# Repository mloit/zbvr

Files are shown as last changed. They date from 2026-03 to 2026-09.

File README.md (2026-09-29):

# Vintage AM Radio Inspired Offline MP3 Player PCB

***Complete PCB design files and documentation coming soon!***

## Announcements 

- ***NEW:*** [26.0.2 firmware](https://github.com/mloit/zbvr-firmware) (Latest release available on the [Releases page](https://github.com/mloit/zbvr-firmware/releases/latest))

- ***New:*** [Big Speaker Option](./docs/Big%20Speaker%20Assembly%20Guide.md)

- ***New*** BOM's for PCB upgrade and battery module (see below)

- ***Coming Soon:*** Battery module PCB and assembly guides

---

Want to support my efforts? Feel free to [Buy me a Coffee][support]
---

## Docs
- [PCB Assembly Guide](./docs/PCB%20Assembly%20Guide.md)

- [Wiring Harness Assembly Guide](./docs/Wiring%20Harness%20Assembly%20Guide.md)

## Errata
A number of boards have been exhibiting a problem when turning on the radio via the potentiometer, the connection to Thonny (or other serial terminal) is lost. This appears to be due to a dip in voltage as a result of the inrush current to charg up the amplifier circuit. To address this I recommend soldering a 100uF electrolytic (Digikey: 1189-2195-ND, or similar) between the 5V and Gnd pins of the GPIO connector (J10) located between the RP-Zero and the DFPlayer

---
## The PCB
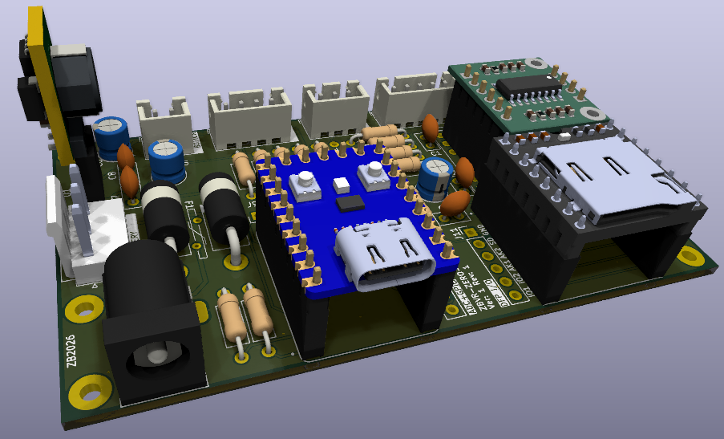
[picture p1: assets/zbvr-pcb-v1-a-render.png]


### Schematic 
(Click Image for PDF)
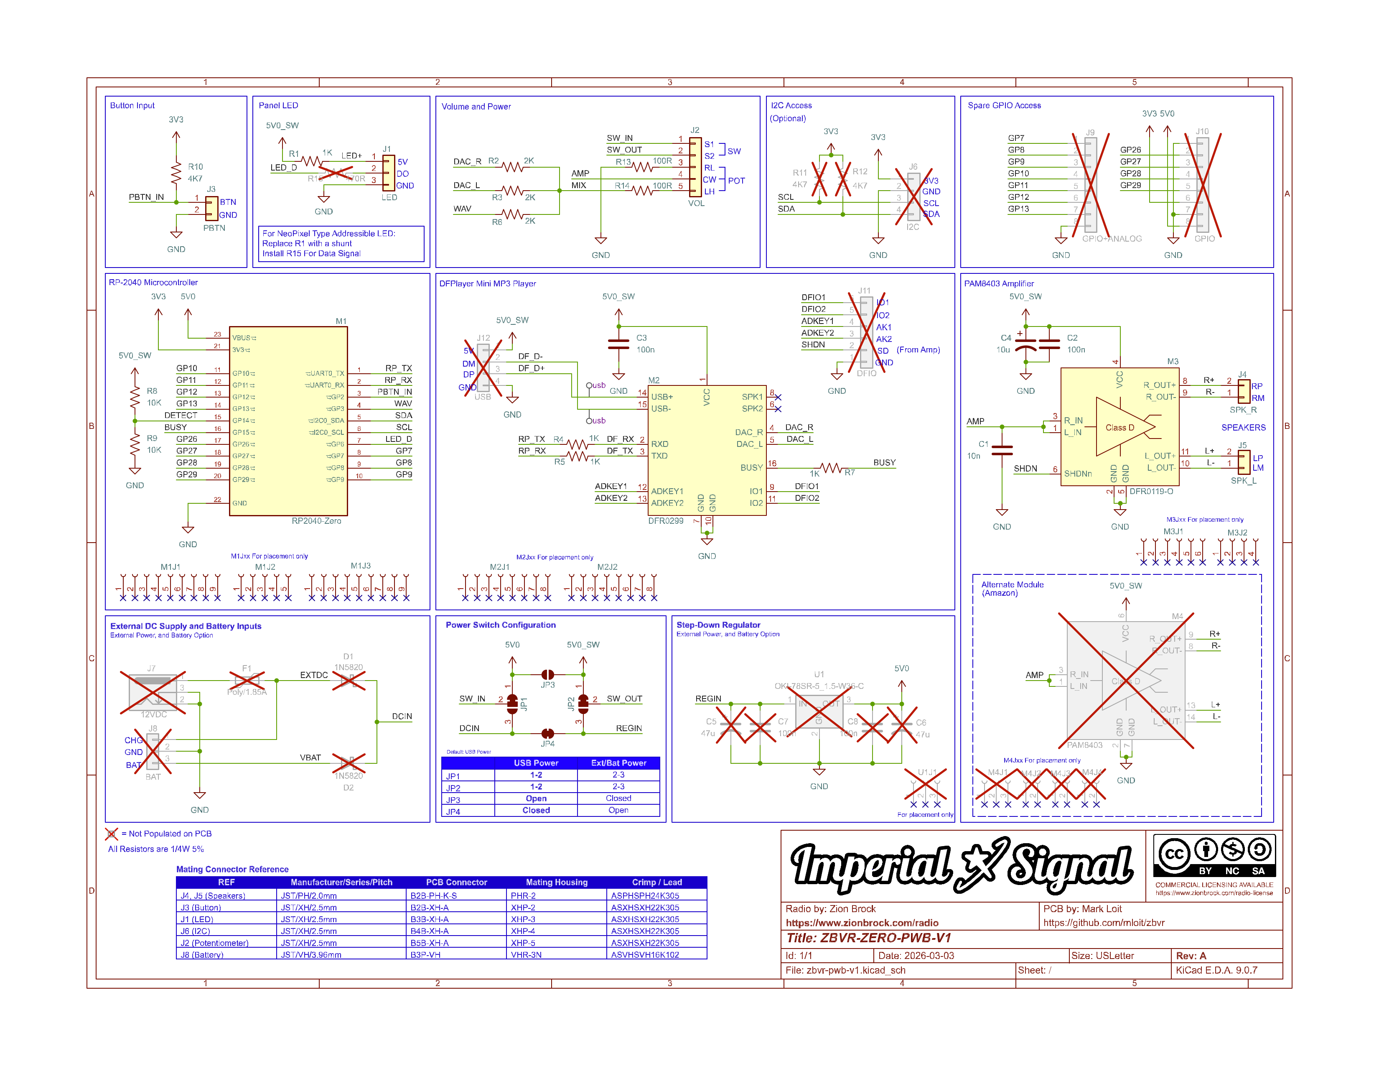
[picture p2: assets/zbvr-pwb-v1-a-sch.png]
[](./assets/zbvr-pwb-v1-a-sch.pdf)

### Top/Component Side of PCB:
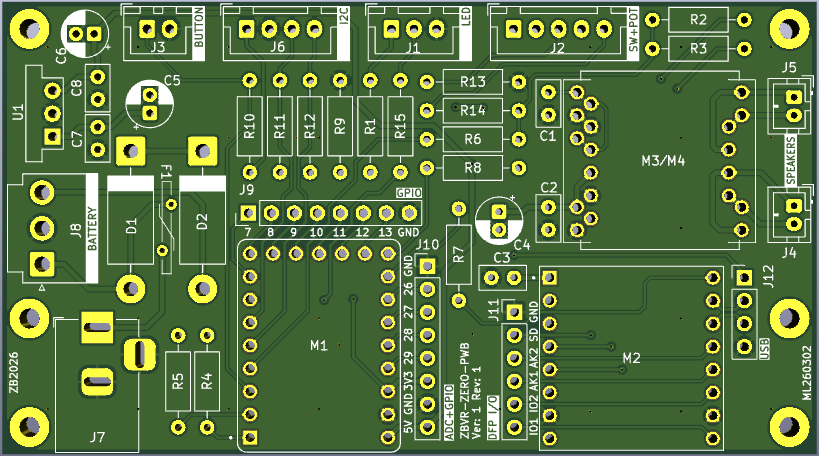
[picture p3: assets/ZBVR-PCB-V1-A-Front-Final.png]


### Bottom/Solder Side of PCB:
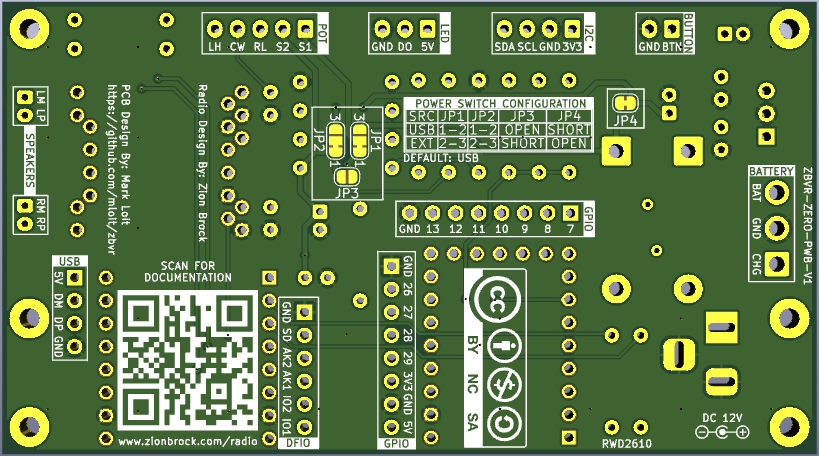
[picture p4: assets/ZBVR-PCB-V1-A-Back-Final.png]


---

## Building your own

The first step to building your own will be to get your hands on a bare PCB. PCB's can currently be ordered from our [Community project at PCBWay][pcbway]. This is currently the preferred route as we do earn a small commission on every board ordered from there to help support the project (anything earned on the PCB's is shared between Zion and myself). Also please note that if you plan to resell the PCB's we ask that you fill out a [license application][zion-lic] on Zion's project site.

For the components you can use this [list at DigiKey][dk-pcb] as a starting point. The list includes everything except the speakers, RP2040-Zero, and push-button, for the basic configuration of the PCB. Details on a more complete configuration for external power and a battery will be provided in the near future.

In terms of the 3D printed parts, for the PCB version you want to print the "Shell Normal - with button" version of the shell, from the "Shells" 3MF profile. From the "Mounts" 3MF profile you want to print the "Circuit Board Mount (PCB Version)" plate. (Optionally, if building for the "Big Speaker Option", you would print that mount instead)  All other radio parts (except for the back plate, see next section) are common, and the same for any version of the device. You may optionally print the "Soldering Aids" 3MF for some jigs and tools to make assembling the PCB a bit easier.

#### Radio Back Plate

Depending on which verion of the PCB you are plannning to build/use the back plate changes. The "Standard" version is powered by USB, while the "Full" version used with the battery option requires an external DC power supply. (The full version can be used without the battery, but still requires the external DC supply) The Full version is not compatable with being powered over USB, as such 2 versions of the back plate have been designed. One with the USB opening for the "Standard" buikd, and one with a hole for the external DC suppply for the "Full" version. Please be sure to print the correct version of the back plate for the version of the PCB you are going to assemble. 

- Standard PCB Build: "Back Plate for PCB Version"
- Full PCB Build: "Back Plate for PCB Battery Version"

#### Battery & Big Speaker Options

Note that the "Big Speaker Option" profile I have here currently does not have mounts for the battery module. I will be updating this soon to add the mounting points. If building now, I recommend using Hook and Loop (Velcro) adhesive fastener strips to attach he battery module to the back of the speaker shell. All versions of the PCB here support the big speaker, so no changes are required on the PCB itself.

Note the BOM's for the battery do NOT include teh external DC supplpy, as it will depend on your region. The requrements are 10W or more power, 9-12V. 5.5mm barrel with 2.1mm pin, centre positive.

- Example for North America: [GlobTek WR9HD1333CCP-F(R6B)][dk-psu-us] (Digikey)

### Before you purchase components
The board is designed to support either the amplifier module from DigiKey, or the amplifier module originally demonstrated by Zion in his video, from Amazon. If you have already purchased components from Amazon, you can omit getting them from the list provided above. Note that if you are going with the Amazon Amplifier this affcts a few lines in the list. With the exception of the items mentioned earlier, this list here effectively replaces teh BOM currently on Zion's site.

#### If you have already purchased, or plan to use the amplifier module from Amazon

**Remove** the following 3 line items:
1. Line 2: DFR0119-O (PAM8403 Eval board) Digikey P/N: 1738-1041-ND
2. Line 26: PPTC041LFBN-RC (1x4 pos female header 2.54mm) Digikey P/N: S7002-ND
3. Line 27: PPTC061LFBN-RC (1x6 pos female header 2.54mm) Digikey P/N: S7004-ND

**Add** the following 2 items:
1. PPTC021LFBN-RC (1x2 pos female header 2.54mm) DigiKey P/N: S7000-ND - Quantity 3 per board
2. PPTC031LFBN-RC (1x3 pos female header 2.54mm) DigiKey P/N: S7001-ND - Quantity 1 per board

#### Notes on the BoM (Bill of Materials)

There are several bills of materials for the PCB, depending on which version you want to build, or are upgrading from one to the other. They all use the same base Radio PCB but are populated differently.

##### Standard Build (USB Powered)

If building the standard version fo the PCB, as featuerd in Zion's original videos about the PCB, you want to use this BOM. (Note that this version does not include support for the battery option)

- [Standard PCB Components][dk-pcb] (DigiKey)
- [Standard PCB Components Alternate][dk-pcb-alt] (DigiKey) -- for when you are using the amplifier from Amazon
- [Amplifier Module][amp] (Amazon) -- Optional/Alternate
- [RP2040-Zero][rp] (Amazon)

##### Full Build (External Powered or Battery Powered)

If you want your radio to be powered by an external DC supply, or be powered by the battery module use this BOM if building a new board. If upgrading an existing board, use the upgrade BOM below. Note that if planning to use the battery module, you need to also get the items in the "Battery Only" BOM below. Note while I have not amde an alternalte BOM for this version, you can make teh same changes as noted above if using the amplifier from Amazon.

- [Full PCB Components][dk-pcb-full] (DigiKey)
- [Amplifier Module][amp] (Amazon) -- Optional/Alternate
- [RP2040-Zero][rp] (Amazon)

**Note:** the BOM does NOT include teh external DC supplpy, as it will depend on your region. The requrements are 10W or more power, 9-12V. 5.5mm barrel with 2.1mm pin, centre positive.

- Example for North America: [GlobTek WR9HD1333CCP-F(R6B)][dk-psu-us] (Digikey)

##### Standard to Full Upgrade (with Battery)

This BOM contains only the components required to upgrade your PCB from the standard configuration to the full configuration, as well as the components for the battery module. Note if building more than one battery board, I recommend not purchasing the "PC4" battery holder on the Digikey BOM and instead ordering them on Amazon.

- [PCB Upgrade and Battery Parts][dk-pcb-upg] (DigiKey)
- [PC4 Battery holder][pc4] (Amazon)
- [Battery Charger Module][chg] (Amazon)
- [Battery Protection Module][prot] (Amazon)

**Note:** the BOM does NOT include teh external DC supplpy, as it will depend on your region. The requrements are 10W or more power, 9-12V. 5.5mm barrel with 2.1mm pin, centre positive.

- Example for North America: [GlobTek WR9HD1333CCP-F(R6B)][dk-psu-us] (Digikey)

##### Battery Only

This BOM contains just the DigiKey parts requred for the Battery Module and teh wiring to connect it to the main board. If upgrading follow the Upgrade BOM above instead. If building for the battery from the start, use the "Full Build" Bom above, and add the items in this BOM to your order as well. Note if building more than one battery board, I recommend not purchasing the "PC4" battery holder on the Digikey BOM and instead ordering them on Amazon.

- [Battery Module Parts][dk-bat] (DigiKey)
- [PC4 Battery holder][pc4] (Amazon)
- [Battery Charger Module][chg] (Amazon)
- [Battery Protection Module][prot] (Amazon)

---

## Project Links:

- [Full Project Homepage][zion-web]
- [PCB page on Zion's website][zion-build]
- [Project Discord][discord]
- [3D Print Files][zion-mw] (MakerWorld)
- [PCB Boards][pcbway] (PCBWay)
- [Standard PCB Components][dk-pcb] (DigiKey)
- [Standard PCB Components Alternate][dk-pcb-alt] (DigiKey) -- for when you are using the amplifier from Amazon
- [Full PCB Components][dk-pcb-full] (DigiKey)
- [PCB Upgrade Components][dk-pcb-upg] (DigiKey)
- [Battery Module Components][dk-bat] (DigiKey)
- [Zion Brock's YouTube][zion-yt]

---

Want to support my efforts? Feel free to [Buy me a Coffee][support]

[](./LICENSE.txt)

[cc-by-nc-sa]: ./assets/by-nc-sa.png "CC-BY-NC-SA"
[sch]: ./assets/zbvr-pwb-v1-a-sch.png "ZBVR-PWB-V1-A Schematic"
[pcb]: ./assets/zbvr-pcb-v1-a-render.png "Rendering of fully populated ZBVR-PCB-V1-A"
[front]: ./assets/ZBVR-PCB-V1-A-Front-Final.png "Top/Component Side of PCB"
[back]: ./assets/ZBVR-PCB-V1-A-Back-Final.png "Bottom/Solder Side of PCB"
[pcbway]: https://www.pcbway.com/project/shareproject/Simple_lo_fi_offline_MP3_player_for_the_Zion_Brock_vintage_radio_official_PCB_5a9d43d7.html
[dk-pcb]: https://www.digikey.com/en/mylists/list/7UZQIHX73I
[zion-web]: https://www.zionbrock.com/radio
[zion-mw]: https://makerworld.com/en/models/2163838-my-vintage-radio-offline-am-style-music-player
[zion-yt]: https://www.youtube.com/@zionbrock/videos
[discord]: https://discord.gg/p7cJ7csKEd
[zion-lic]: https://www.zionbrock.com/radio-license
[zion-build]: https://www.zionbrock.com/vintage-radio-circuit-board-pcb
[dk-pcb-alt]: https://www.digikey.com/en/mylists/list/B0VSUA3P00
[dk-pcb-full]: https://www.digikey.com/en/mylists/list/RAMKQWNZRU
[dk-pcb-upg]: https://www.digikey.com/en/mylists/list/QIRFQ48IGT
[dk-bat]: https://www.digikey.com/en/mylists/list/4W6Q9O6ATI
[dk-psu-us]: https://www.digikey.ca/en/products/detail/globtek-inc/WR9HD1333CCP-F-R6B/13245472
[rp]: https://www.amazon.com/dp/B0C5Q2V49P?ref=ppx_yo2ov_dt_b_fed_asin_title&th=1
[amp]: https://www.amazon.com/HiLetgo%C2%AE-PAM8403-Digital-Amplifier-2-5-5V/dp/B00LODGV64/ref=sr_1_1_sspa?th=1
[pc4]: https://www.amazon.com/dp/B0B1JJZ363?ref=ppx_yo2ov_dt_b_fed_asin_title&th=1
[chg]: https://www.amazon.com/Bloepum-Charging-Management-Lithium-Battery/dp/B0FB8K6PVR
[prot]: https://www.amazon.com/dp/B0DDY32WF4?ref=ppx_yo2ov_dt_b_fed_asin_title
[support]: https://buymeacoffee.com/canadianavenger

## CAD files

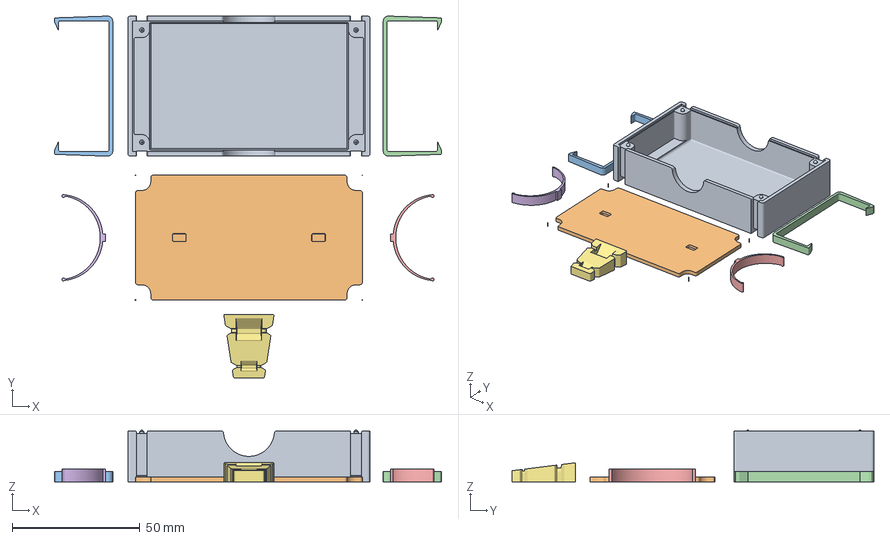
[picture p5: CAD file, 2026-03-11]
assets/assembly-jigs.3mf
151.9 x 142.0 x 20.3 mm
soldering aid.stl
soldering-aid-plate.stl
soldering-aid-clip.stl x 2
soldering-aid-spring.stl x 2
bend-aid-new.stl

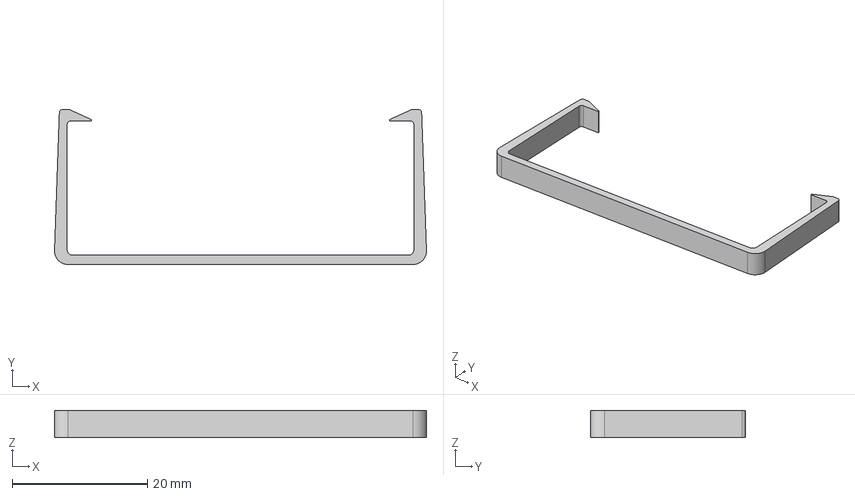
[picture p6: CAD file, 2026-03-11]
3D CAD Models/soldering aids/soldering-aid-clip.step
55.0 x 22.9 x 4.00 mm

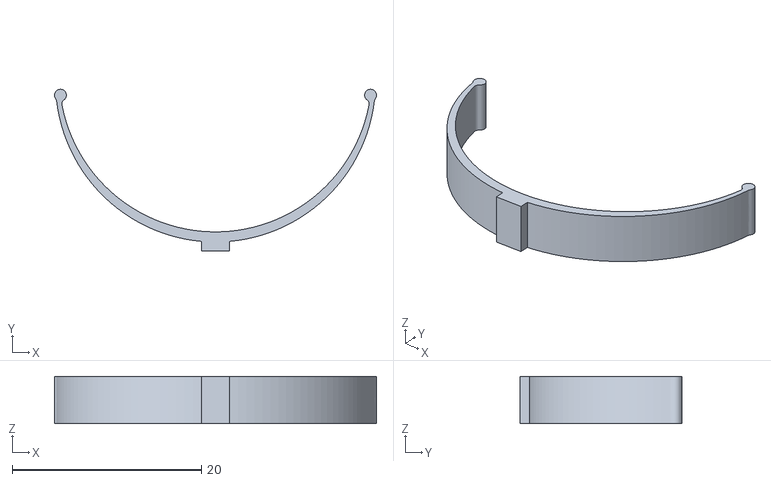
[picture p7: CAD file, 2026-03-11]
assets/soldering-aids/soldering-aid-spring.stl
34.0 x 17.1 x 5.00

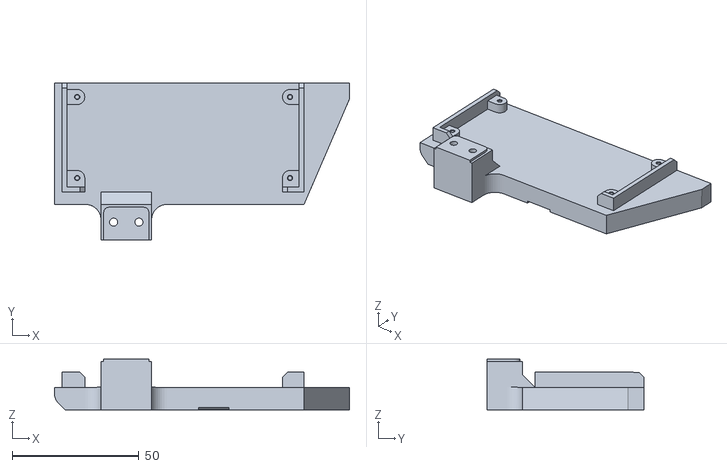
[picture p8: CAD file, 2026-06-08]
assets/speaker/mount-big-spkr.stl
116.4 x 61.9 x 20.0

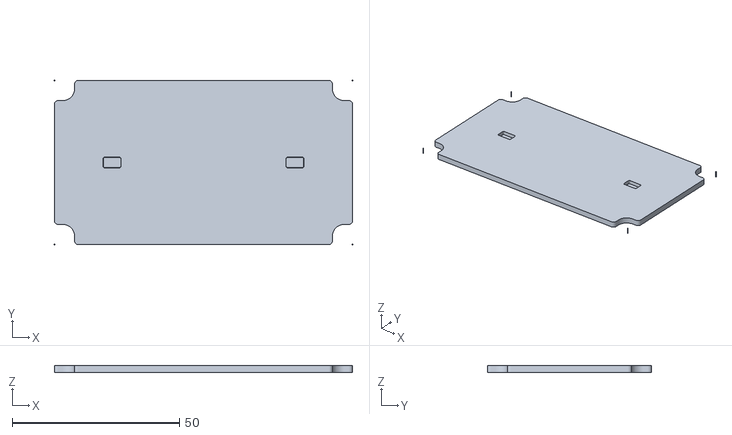
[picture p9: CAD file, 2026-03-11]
assets/soldering-aids/soldering-aid-plate.stl
89.0 x 49.0 x 2.00

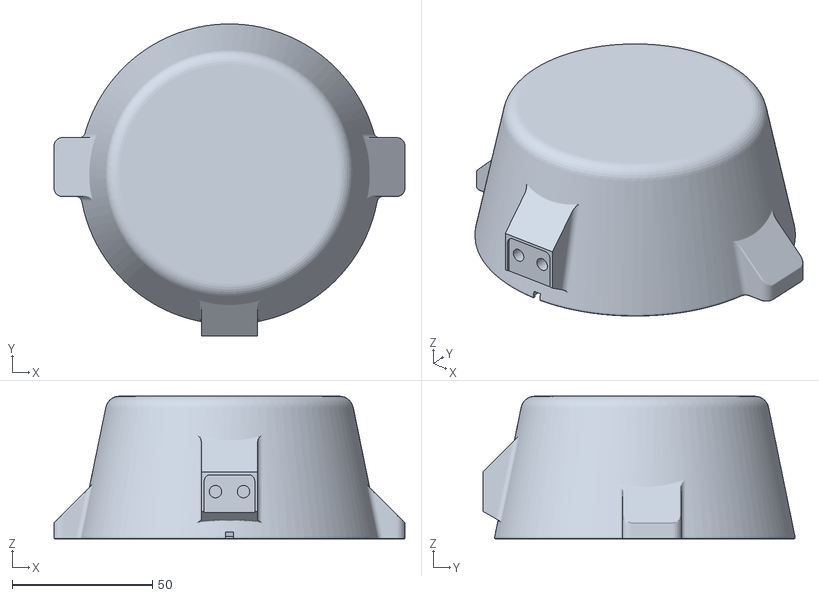
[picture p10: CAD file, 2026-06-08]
assets/speaker/GRS-3AS-4-cup.stl
125.0 x 111.1 x 50.8

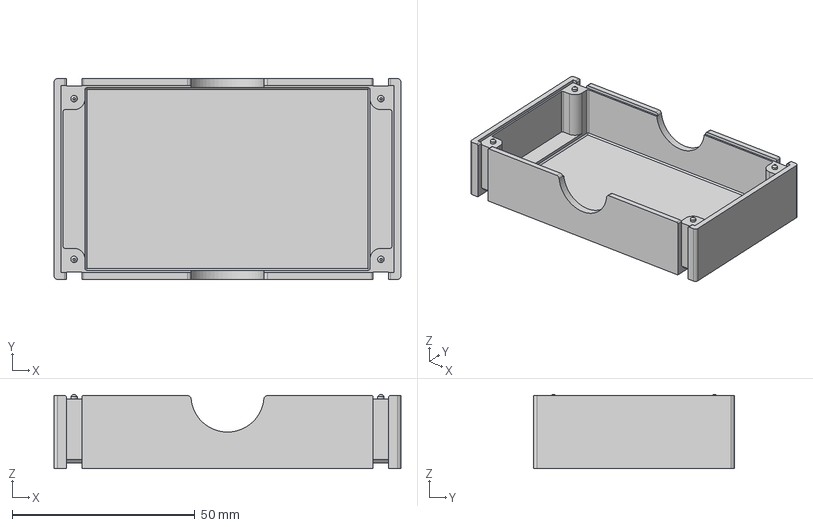
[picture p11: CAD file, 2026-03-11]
3D CAD Models/soldering aids/soldering aid.step
95.0 x 55.0 x 20.3 mm

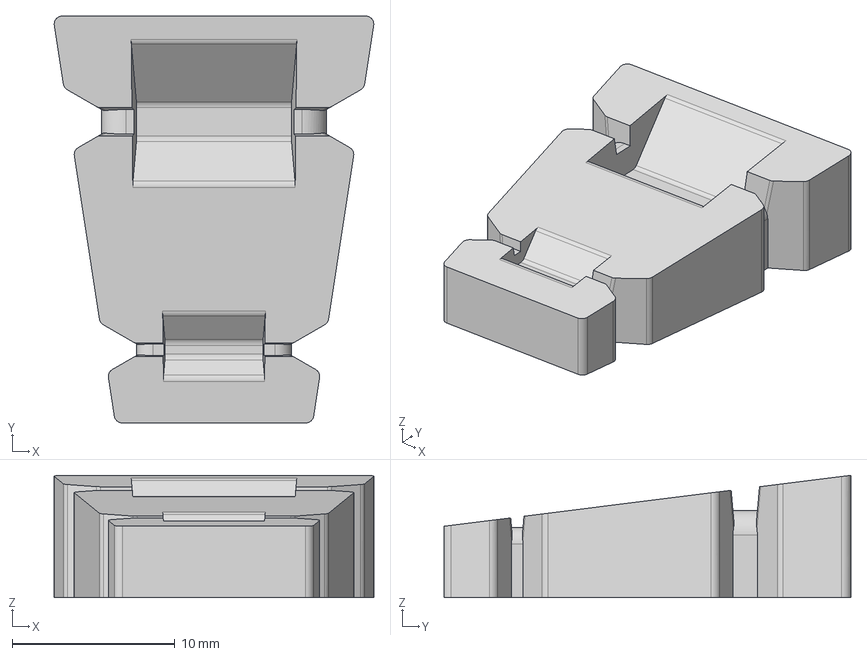
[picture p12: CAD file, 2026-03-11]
3D CAD Models/soldering aids/bend-aid-new.step
19.6 x 25.0 x 7.52 mm

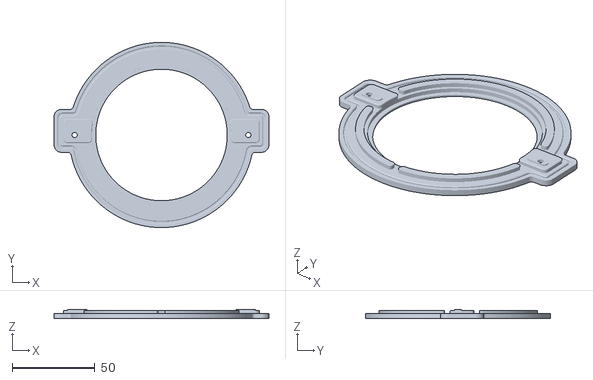
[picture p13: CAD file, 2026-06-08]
assets/speaker/GRS-3AS-4-ring.stl
130.0 x 112.0 x 5.60

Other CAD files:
3D CAD Models/soldering aids/soldering-aid-spring.step
assets/soldering-aids/soldering-aid-clip.stl
assets/soldering-aids/soldering-aid.stl
3D CAD Models/soldering aids/soldering-aid-plate.step
assets/soldering-aids/bend-aid-new.stl

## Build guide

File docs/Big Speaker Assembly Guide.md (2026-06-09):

# Big Speaker Assembly Guide

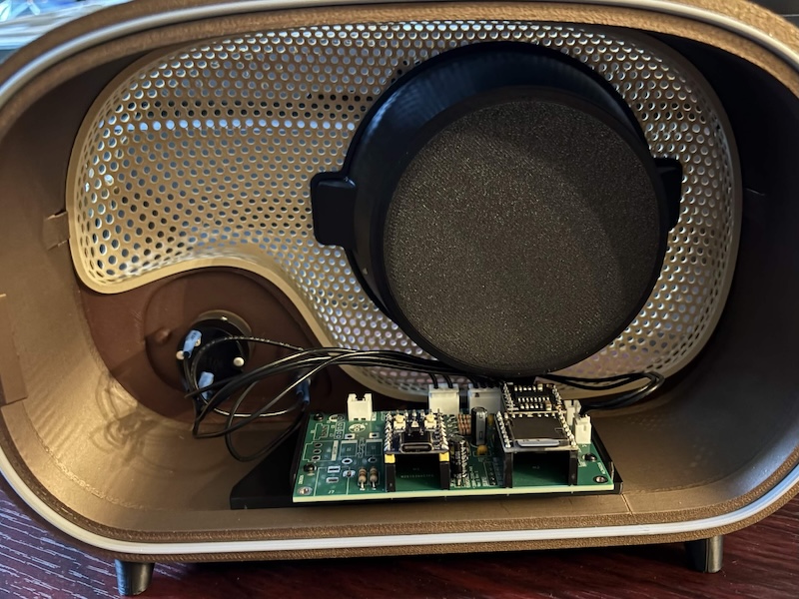
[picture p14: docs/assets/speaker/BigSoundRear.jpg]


So you build the [radio with the PCB][1], but wanted bigger sound from it. This guide is here to help with that. I've designed a new mount and enclosure for a 3.5in car speaker that is fairly inexpensive, and fairly easy to obtain. The solution here isn't perfect, but sounds quite good. The only real downside is that the PCB needs to be mounted on the mount and the potentiometer plugged in before the speaker can be mounted. (you may want to have the LED connected as well beforehand) 

[1]: https://www.zionbrock.com/radio
[begin]: ./assets/speaker/BigSoundRear.jpg "Assembled Speaker and Mount"

---

## Materials

- 1x 3D Printed speaker mount and enclosure
	- [All Parts 3MF](/assets/speaker/big-speaker.3mf) 
	- [All Parts STL/ZIP](/assets/speaker/big-speaker.zip)
	- Individual STL files
		- 1x [Mount](/assets/speaker/mount-big-spkr.stl)
		- 1x [Speaker Cup](/assets/speaker/GRS-3AS-4-cup.stl)
		- 1x [Face Ring](/assets/speaker/GRS-3AS-4-ring.stl)
- 6x M3 Threaded heat-set insert nuts
	- [Maker World M3x5x4](https://ca.store.bambulab.com/products/round-threaded-brass-heat-insert-nut) AB012
	- [CNC Kitchen M3x5x4](https://cnckitchen.store/products/made-for-voron-gewindeeinsatz-threaded-insert-m3x5x4-100-stk-pcs)
- 2x M3x6 SHCS (Socket Head Cap Screws) - for mounting assembly in radio
	- [Maker World M3x6 SHCS](https://ca.store.bambulab.com/products/m3-socket-head-cap-machine-screws-shcs-1) AA036
- 2x M3x10 SHCS (Socket Head Cap Screws) - attaching speaker to mount
	- [Maker World M3x10 SHCS](https://ca.store.bambulab.com/products/m3-socket-head-cap-machine-screws-shcs-1) AA159
- 2x M3x8 BHCS (Button Head Cap Screws) - attaching ring to cup
	- [Maker World M3x8 BHCS](https://ca.store.bambulab.com/products/m3-button-head-cap-machine-screws-bhcs) AA058
- 4x BT2x6 SHCSST (Socket Head Cap Screw Self Tapping) - Attaching PCB to mount
	- [Maker World BT2x6 SHCS](https://ca.store.bambulab.com/products/bt2-socket-head-cap-self-tapping-screws-shcs-new) AA093
	- [Maker World BT2x6 BHCS](https://ca.store.bambulab.com/products/bt2-button-head-cap-self-tapping-screw-bhcs) AA128 (Old Button Head Version) 
- 1x GRS 3AS-4 3.5in automotive replacement speaker 4 ohm 15 Watts
	- [Parts Express](https://www.parts-express.com/GRS-3AS-4-3-1-2-Car-Replacement-Speaker-4-Ohm-292-452?quantity=1) (USA)
	- [Solen Online](https://www.solen.ca/en/products/GRS-3AS-4-87mm-Car-Replacement-Speaker-4-Ohm) (Canada)
	- [Sound Imports](https://www.soundimports.eu/en/grs-3as-4.html) (Europe)
- 1x JST PHR-2 - PH Series 2mm pitch 2 pin housing
	- Not needed if salvaging from old speaker
	- [Digikey 455-1165-ND](https://www.digikey.com/short/q53mh2v7)
	- [Mouser 306-PHR-2PP](https://mou.sr/4vBqxXr)
- 1x JST ASPHSPH24K305 - PH Series crimped 12in 24AWG lead
	- Not needed if salvaging from old speaker
	- [Digikey 455-3083-ND](https://www.digikey.com/short/qd985ztp)
	- [Mouser 306-ASPHSPH24K305](https://mou.sr/48MVWfJ)

***Note:*** *If salvaging the wire and connector from an old speaker, be sure to cut as close to the speaker as possible, you want to end up with at least 6in of wire from the cut end to the connector.*

### Additional Required Materials

- Solder

### Optional Materials

- Sealant or Glue
	- Hot Glue
	- Silicone
	- Epoxy 

## Tools
### Required Tools

- Soldering Iron
- Wire Cutters
- Wire Strippers

### Optional Tools

- Hot Glue Gun

---

## Assembly

### Mount Preparation

We'll start by installing the heat-set insert nuts

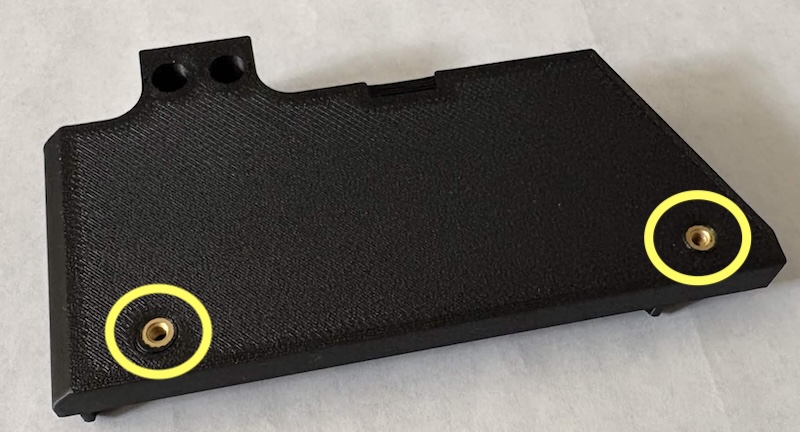
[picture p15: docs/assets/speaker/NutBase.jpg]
1. Install the heat-set nuts into the bottom of the mount as shown.<br>
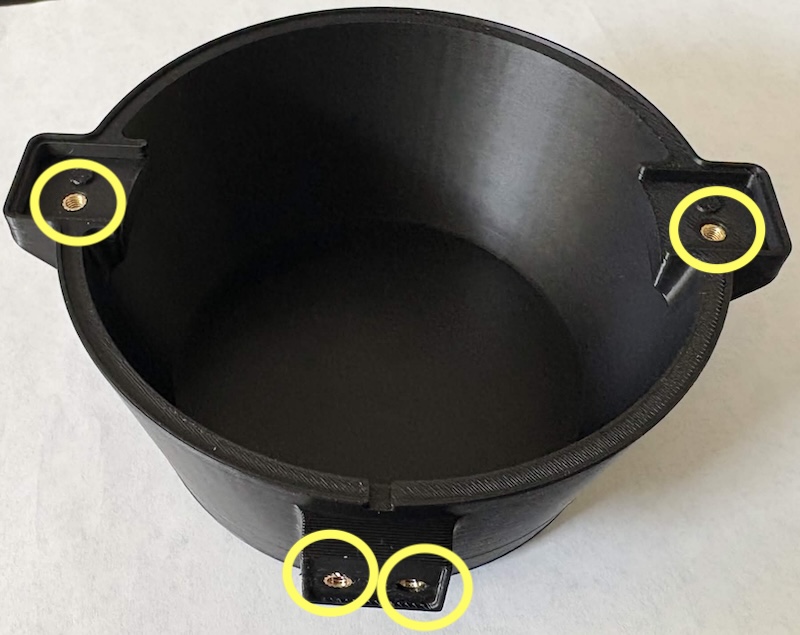
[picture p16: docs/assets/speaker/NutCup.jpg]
2. Install the heat-set nuts into the speaker cup as shown.<br>

[nut1]: ./assets/speaker/NutBase.jpg "Locations for heat inserts in mount base"
[nut2]: ./assets/speaker/NutCup.jpg "Locations for heat inserts in speaker cup"

### Speaker Preparation

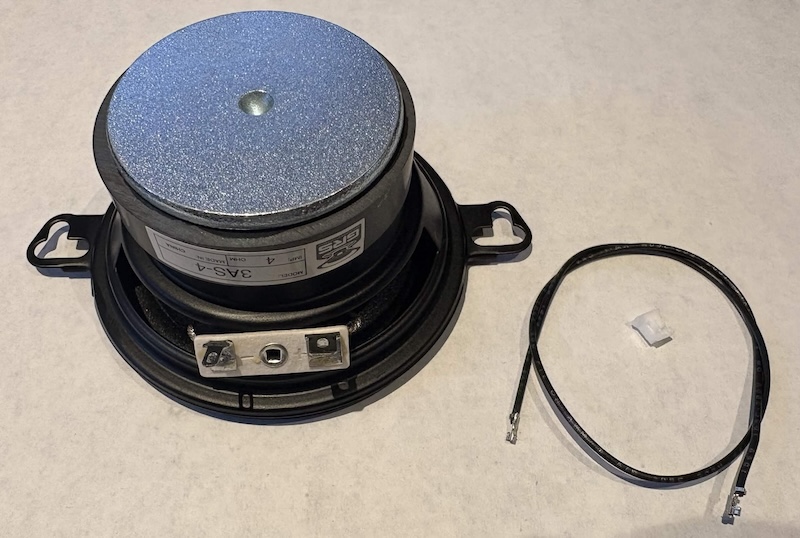
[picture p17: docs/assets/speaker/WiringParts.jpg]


Next we need to add wire leads to the speaker

1. Fold and cut the 12in wire lead in half to produce two 6in wire leads, each with a crimp on one end.
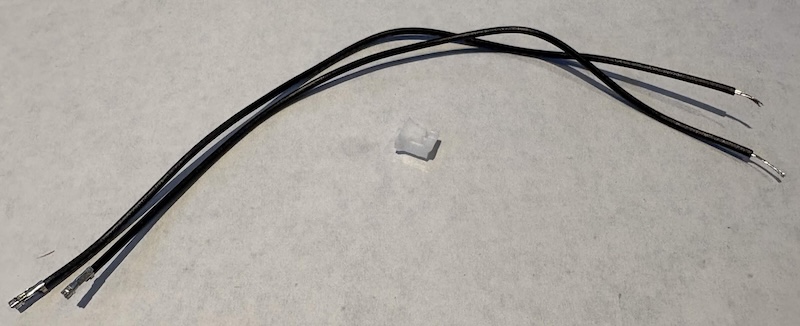
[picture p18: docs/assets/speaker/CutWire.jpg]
2. Strip the bare end of the wire exposing 3-5mm of the bare wire.<br>
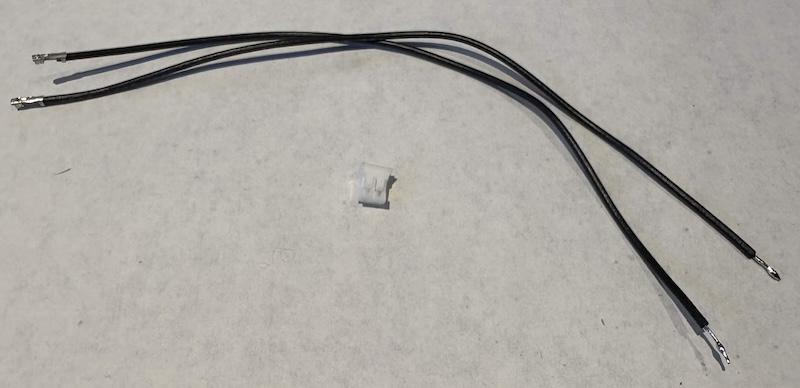
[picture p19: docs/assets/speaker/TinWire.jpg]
3. Tin the stripped wire ends with some solder.<br>
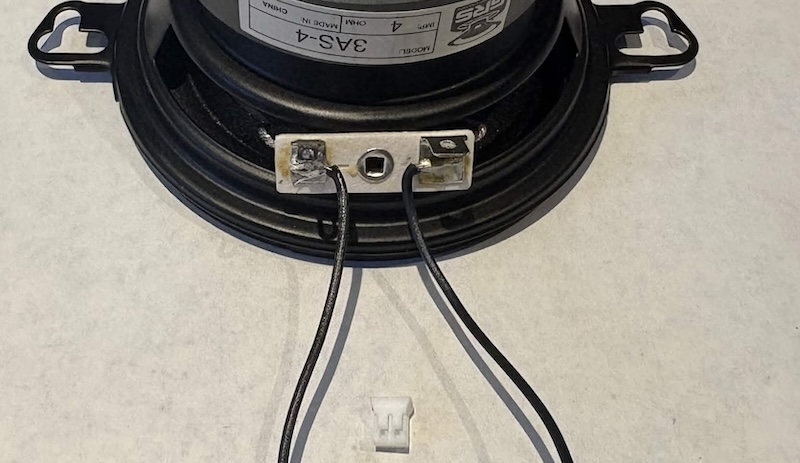
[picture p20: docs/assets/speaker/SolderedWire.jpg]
4. Solder the leads to the speaker.I find it easiest to solder to the base of the terminals where there is solder already.<br>
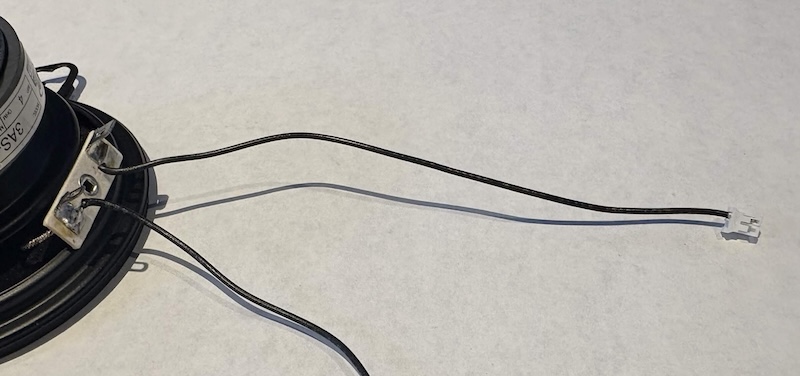
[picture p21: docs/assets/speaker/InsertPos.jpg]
5. Insert the positive lead into pin 2 of the connector housing. *(Note: polarity is not strictly important here as we only have one speaker)*<br>
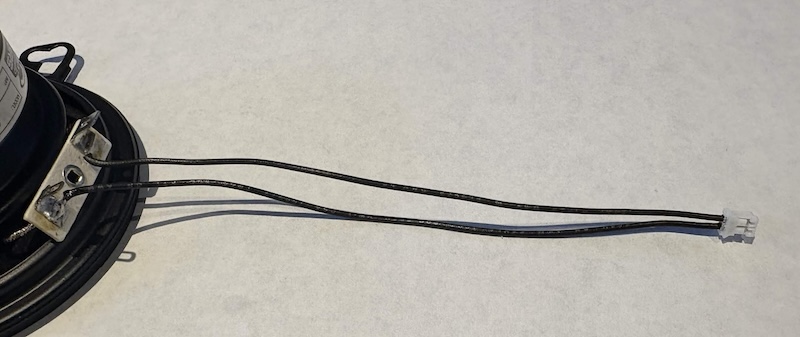
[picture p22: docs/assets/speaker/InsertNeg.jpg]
6. Insert the negative lead into pin 1 of the connector housing.<br>

[wir1]: ./assets/speaker/WiringParts.jpg "Speaker wiring parts"
[wir2]: ./assets/speaker/CutWire.jpg "Cut and stripped wire leads"
[wir3]: ./assets/speaker/TinWire.jpg "Tinned leads"
[wir4]: ./assets/speaker/SolderedWire.jpg "Wires soldered to speaker"
[wir5]: ./assets/speaker/InsertPos.jpg "Positive lead installed in connector"
[wir6]: ./assets/speaker/InsertNeg.jpg "Both leads installed in connector"

### Speaker Enclosure

Next we will assemble the speaker enclosure. The optional step of sealing around the edge is to secure the top ring better, and will prevent any rattle, as well as it should increase the performance of the enclosure slightly.

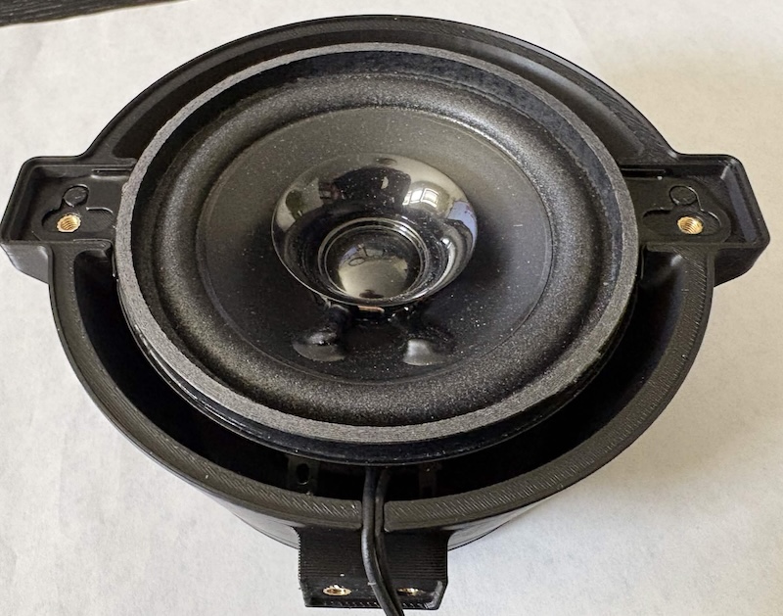
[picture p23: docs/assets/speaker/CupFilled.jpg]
1. First place the speaker  into the cup, using the bumps and slots for alignment. The wires on the speaker should be facing the small slot at the bottom, and pressed down into the slot.<br>
2. Place the Face Ring over the speaker. ***Note:*** *The tabs on the speaker are slightly off-centre so it will only fit one way.*
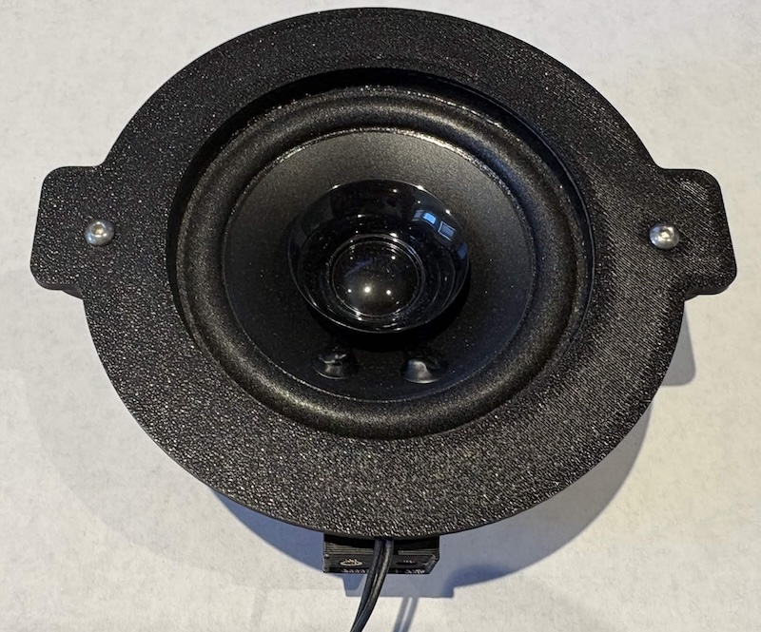
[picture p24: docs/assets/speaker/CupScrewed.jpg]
3. Install the two M3x8 BHCS screws to attach the face and secure the speaker.<br>
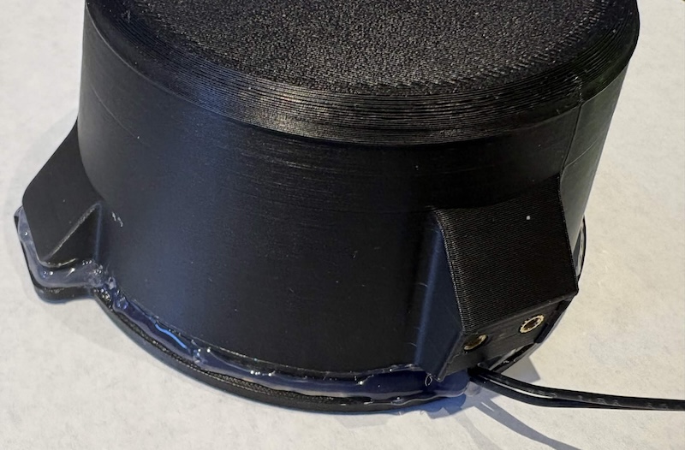
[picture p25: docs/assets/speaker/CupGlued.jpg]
4. *(Optional)* Flip the assembly over and apply a bead of sealant (epoxy/silicone/hot glue) around the perimeter where the cup and face ring meet.<br>

[cup1]: ./assets/speaker/CupFilled.jpg "Speaker placed in the enclosure cup"
[cup2]: ./assets/speaker/CupScrewed.jpg "Front face installed and secured with screws"
[cup3]: ./assets/speaker/CupGlued.jpg "Detail of seal around perimeter"

### Final Assembly
Now we're ready to bring all the parts together.
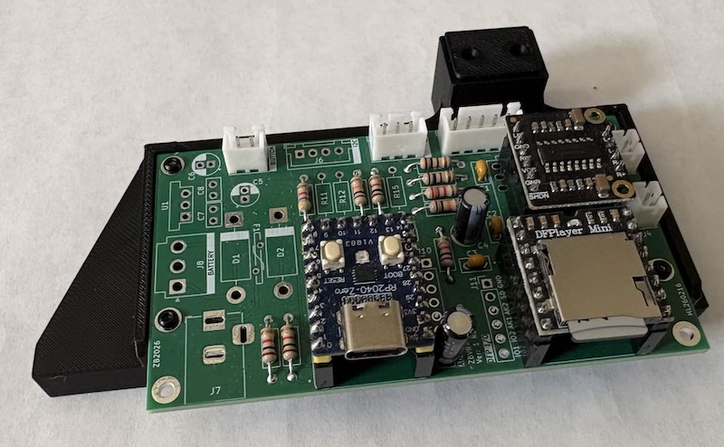
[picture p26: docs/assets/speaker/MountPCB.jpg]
1. Install the PCB onto the mount base using the 4 BT2 SHCS (or BHCS) screws in the corners. *(One of the corners will be inaccessible once the speaker is mounted)*<br>
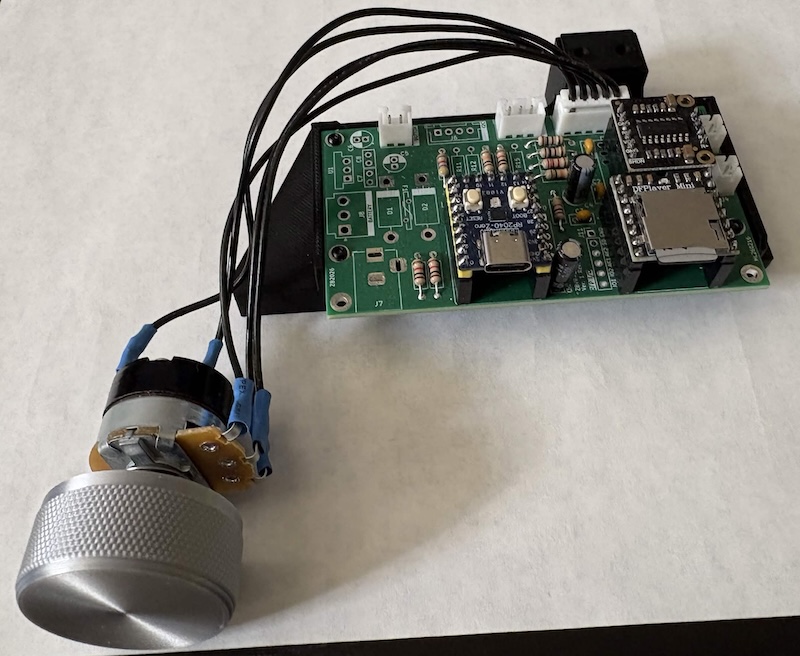
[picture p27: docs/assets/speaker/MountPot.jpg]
2. Connect the potentiometer to the PCB as the connector will be inaccessible once the speaker is mounted. *Note: You may wish to install the LED at this point as well, as access to that connector will be tight after the speaker is mounted*
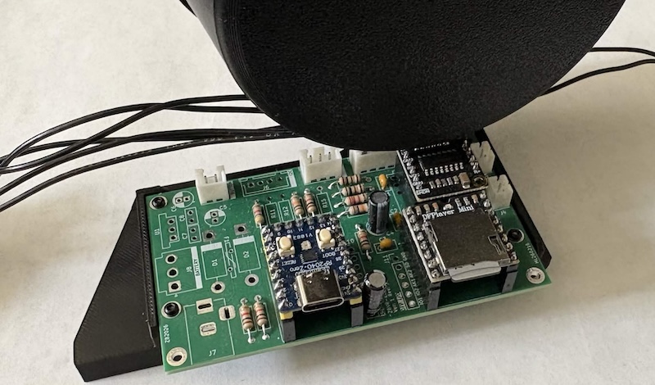
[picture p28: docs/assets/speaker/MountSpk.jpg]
3. Mount the speaker assembly onto the base using the two M3x10 SHCS screws from the base into the speaker assembly. Note there is a bit of a keying emboss on the top of the base "tower" and the bottom of the speaker mounting tab to help align things. 
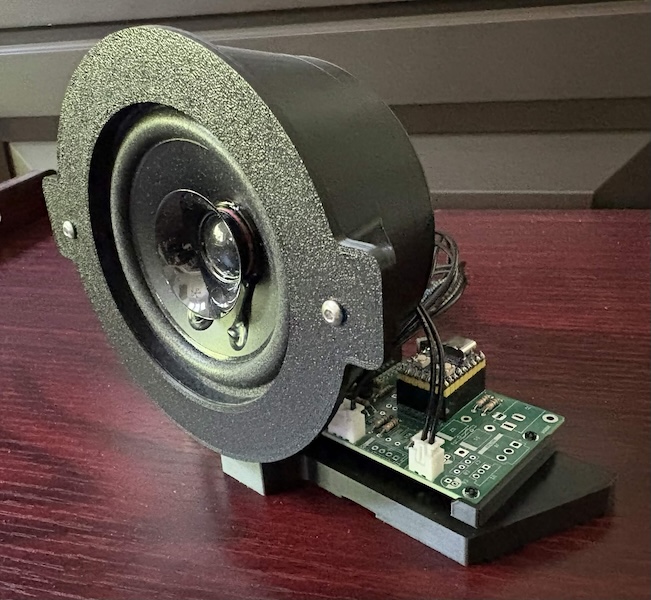
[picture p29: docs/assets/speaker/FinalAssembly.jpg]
4. Plug the speaker into either of the speaker outputs of the PCB

[mnt1]: ./assets/speaker/MountPCB.jpg "Radio PCB installed on base"
[mnt2]: ./assets/speaker/MountPot.jpg "PCB with potentiometer installed"
[mnt3]: ./assets/speaker/MountSpk.jpg "Assembly with speaker mounted"
[mnt4]: ./assets/speaker/FinalAssembly.jpg "assembled speaker mount"

And that's it, at this point the assembly can be installed into the radio using the two remaining M3x6 SHCS screws. 

Enjoy the fuller and louder sound!

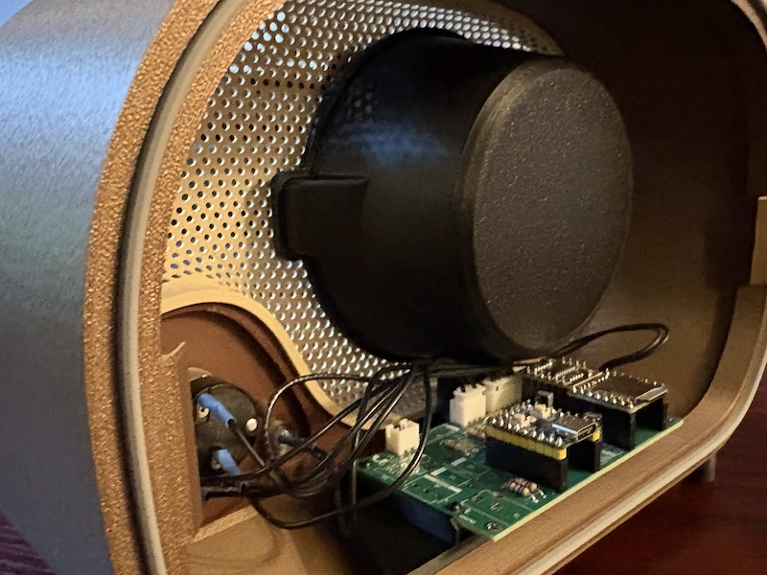
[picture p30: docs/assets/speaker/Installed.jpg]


[fin]: ./assets/speaker/Installed.jpg "Assembly installed inside radio"

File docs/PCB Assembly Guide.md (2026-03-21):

# PCB Assembly Guide

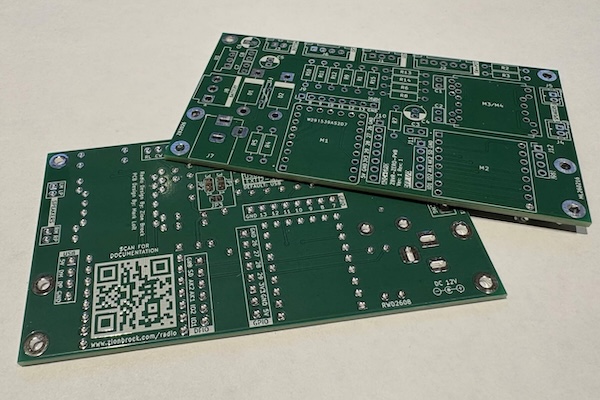
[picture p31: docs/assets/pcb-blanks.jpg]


So you've bought the PCB, and a pile of parts, now what? Now the fun begins! 

This guide is intended for beginners, but is not a tutorial on how to solder. There are plenty of good resources out there already for that. Instead this guide will just walk through the process of populating the board. Intermediate and advanced readers will likely want to just go from the [schematics][1]. 

Note that this guide will produce a board that is populated to be essentially equivalent to what Zion featured in his original videos with the breadboard. There are positions for more components on the board for various build options, mainly support for a battery pack, which will be released in the near future. If you will want to go with the battery option, it will be made as an upgrade path for the current board, so there is no harm in building this configuration first.

[1]: /assets/zbvr-pwb-v1-a-sch.pdf
[begin]: ./assets/pcb-blanks.jpg "blank radio PCB boards"

---

## Materials
### PCB Only Bill Of Materials
All items below (except the RP2040-Zero) can be purchased via this [list at DigiKey][2] The list includes additional items not listed here, but are used later in the radio assembly.

#### Soldered Components

- 2x 100 ohm resistor
- 4x 1K resistor
- 3x 2K resistor
- 1x 4K7 resistor
- 2x 10K resistor
- 1x 10nF capacitor (`103` / 10000pF)
- 2x 100nF capacitor (`104` / 0.1uF)
- 1x 10uF Capacitor
- 2x JST PH series 2 pin connector (`B2B-PH-K-S`)
- 1x JST XH series 2 pin connector (`B2B-XH-A`)
- 1x JST XH series 3 pin connector (`B3B-XH-A`)
- 1x JST XH series 5 pin connector (`B5B-XH-A`)
- 1x 1x4 pin female header (`PPTC041LFBN-RC`) *
- 1x 1x5 pin female header (`PPTC051LFBN-RC`)
- 1x 1x6 pin female header (`PPTC061LFBN-RC`) *
- 2x 1x8 pin female header (`PPTC081LFBN-RC`)
- 2x 1x9 pin female header (`PPTC091LFBN-RC`)

***Note:*** Items Marked with the `*` are intended for the `DFR0119-O` amplifier module in my DigiKey Bill of Materials. If you are using the generic `PAM8403` based amplifier from Amazon (or other source) that is in the original Zion Brock Bill of Materials, replace the two marked items with the following:
-  3x 1x2 pin female header (PPTC021LFBN-RC)
-  1x 1x3 pin female header (PPTC031LFBN-RC)

#### Plugged in Modules

- 1x `RP2040-Zero` microcontroller module
- 1x `DFR0299` DFRobot DFPlayer-Mini module
- 1x `DFR0119-O` DFRobot PAM8403 amplifier module 

### Required Materials

- Solder	

### Optional Materials

- solder wick / Desoldering braid

## Tools
### Required Tools

- Soldering Iron
- Wire Cutters

### Optional Tools

- 3D printed lead bending jig [files & instructions](#bender)
- 3D printed PCB holder [files & instructions](#holder)
- Solder Sucker
- Tweezers
- Digital Volt Meter

[2]: https://www.digikey.com/en/mylists/list/7UZQIHX73I

---

## Assembly

### Module Headers

Before we begin on the PCB itself, now is a great time to take advantage of the blank PCB to act as a jig to help align the headers that need to be soldered on the modules. So if any of your modules (RP-Zero, DFPlayer, or amplifier) came without the header pins pre-soldered, now is the time to do it.

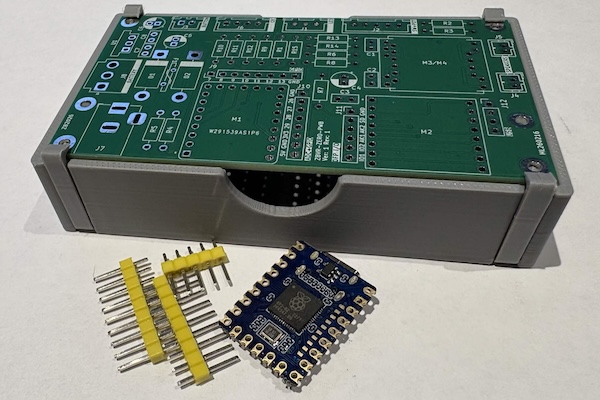
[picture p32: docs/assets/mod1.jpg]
1. Start by installing the blank PCB, component side up, into the 3D printed PCB holder -- without the spring-plate installed. <br>
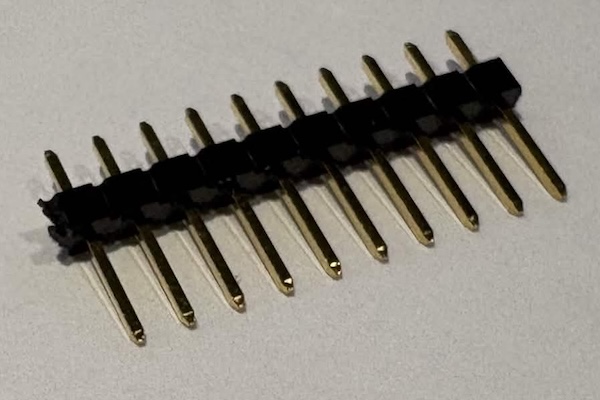
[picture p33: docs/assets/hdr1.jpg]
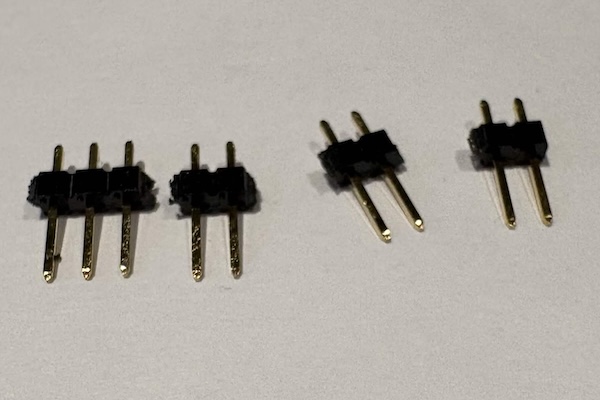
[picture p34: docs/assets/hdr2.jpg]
2. If you have a single long header strip, you need to cut it into the required lengths at the notches. You can use your wire cutters for this. <br>
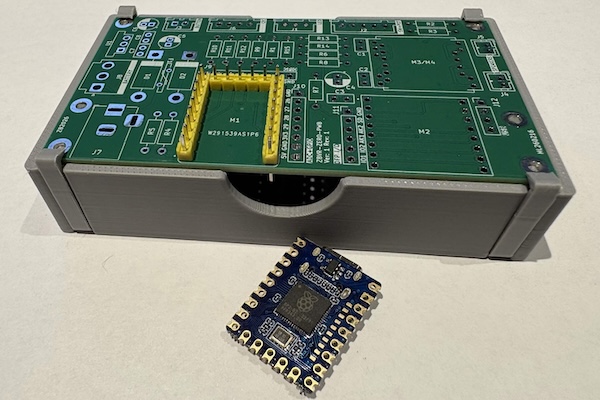
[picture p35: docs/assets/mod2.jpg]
3. Drop the header pins into the corresponding holes on the PCB, long side down. <br>
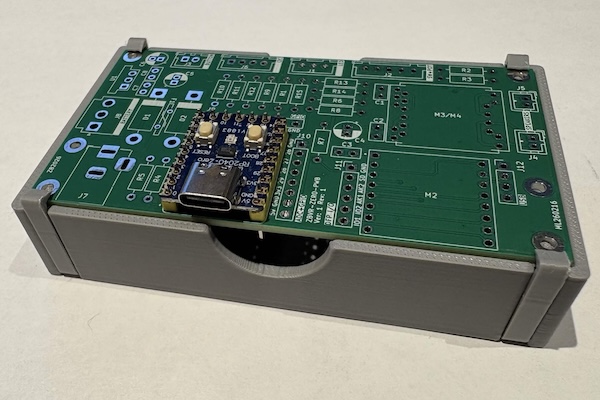
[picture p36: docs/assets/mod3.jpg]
4. Place the module over the pins <br>
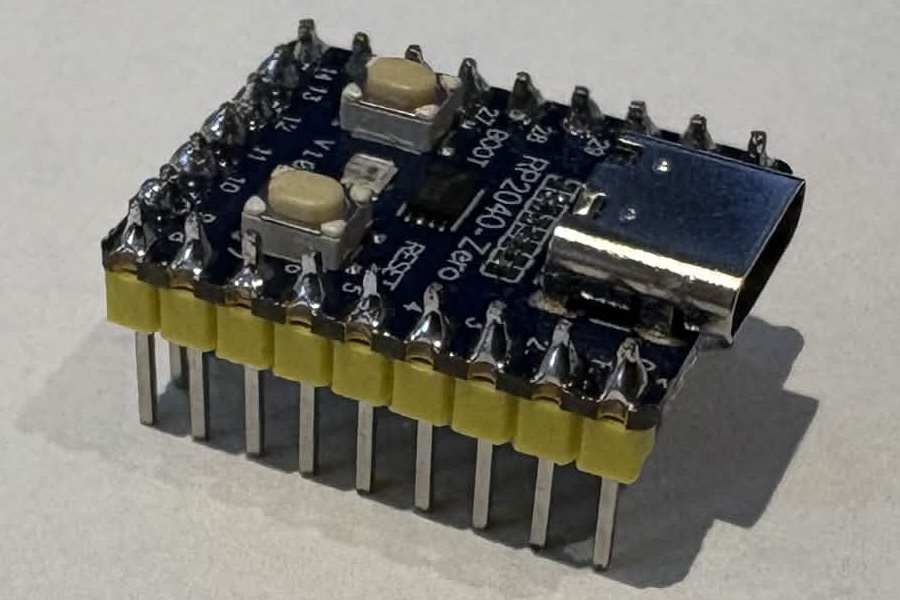
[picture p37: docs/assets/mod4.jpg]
5. Solder the pins. <br>

Do this for all your modules that need to have pins soldered. Having the pins-pre-soldered on the modules will come in handy later.

Set the modules aside for now.

[mod1]: ./assets/mod1.jpg "Blank PCB in holder"
[mod2]: ./assets/mod2.jpg "Blank PCB in holder with header pins installed"
[mod3]: ./assets/mod3.jpg "Blank PCB in holder with header pins and module in place"
[mod4]: ./assets/mod4.jpg "Blank PCB in holder with header pins soldered on module"
[hdr1]: ./assets/hdr1.jpg "uncut header row"
[hdr2]: ./assets/hdr2.jpg "header cut into various lengths"

---

### PCB Soldering

The general process for soldering the PCB will consist of moving from the shortest height components to the tallest. As such, for the components we have, our order will be.

- Resistors
- Small Capacitors
- Speaker Connectors
- Front Panel Connectors (Pot, LED, Button)
- Module Headers
- Large Capacitors

If using the soldering jig, you will want the spring loaded plate to be installed for the remainder of the steps.

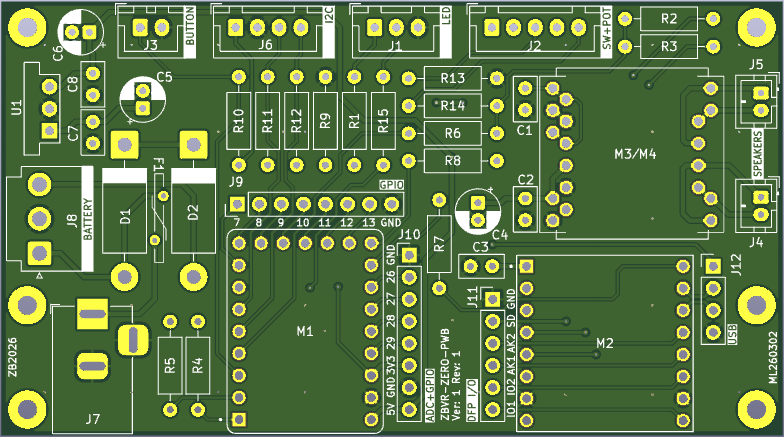
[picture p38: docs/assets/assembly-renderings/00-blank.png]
Blank PCB Rendering


When installing components with long leads (resistors and capacitors), you can bend the leads slightly out (away from the centre of the part) or in (towards the centre of the part). This will help prevent the part from falling out when you flip the board over.

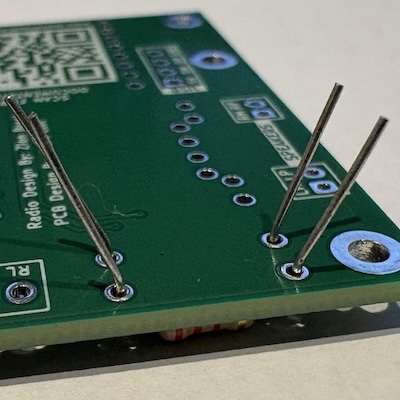
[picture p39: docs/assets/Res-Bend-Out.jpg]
Photo showing leads bent out
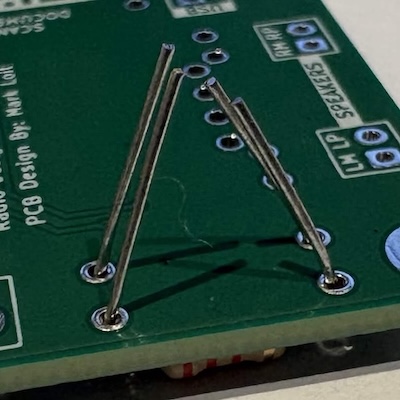
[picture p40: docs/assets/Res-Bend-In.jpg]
Photo showing leads bent in
 

#### Resistors

While we don't have a huge number of resistors, they are all contained in a pretty close area, as such we'll solder the resistors in 2 phases to keep from having too many long leads getting in our way. You may want to use the bending jig to bend the resistor leads before inserting into the board. If you bulk pre-bend them, just be sure to keep track of which is which. Also note that resistors do not have a defined polarity, so the orientation of them in the PCB does not matter.

##### Vertical Group
To keep things easy, we'll group the resistors by overall orientation, we'll tackle the vertical ones first.

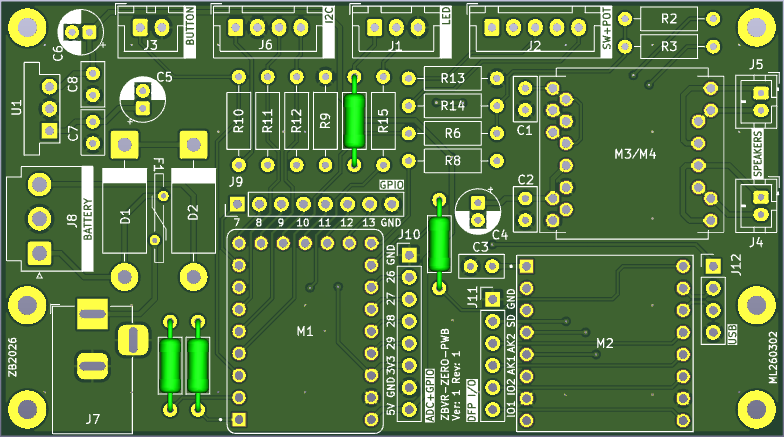
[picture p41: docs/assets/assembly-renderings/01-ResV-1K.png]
1. 1K: R1, R4, R5, R7 <br>
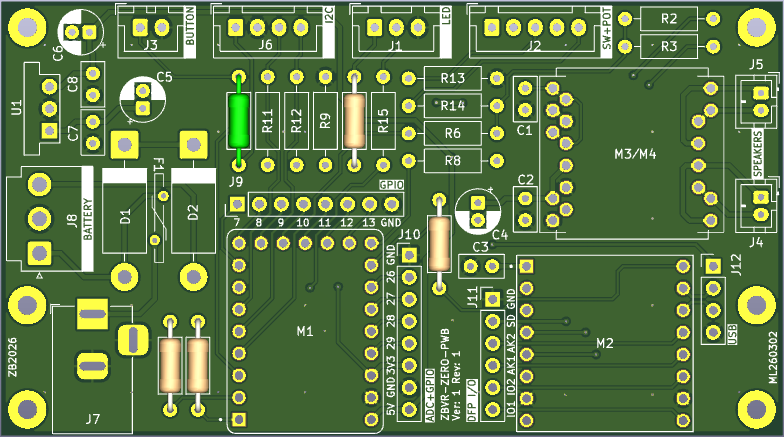
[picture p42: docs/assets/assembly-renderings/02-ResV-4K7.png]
2. 4K7: R10 <br>
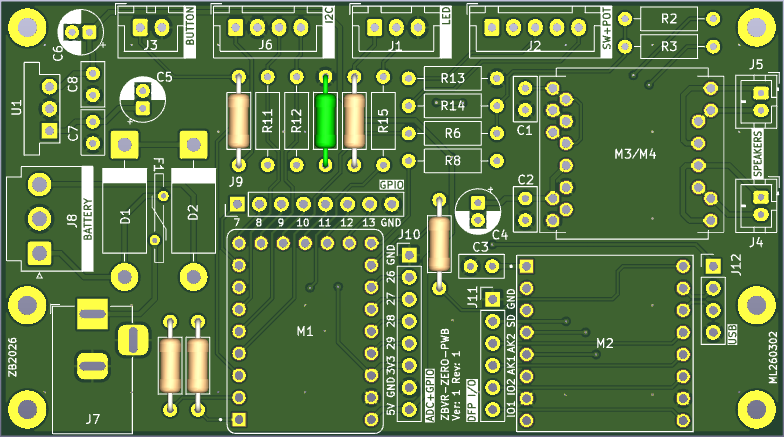
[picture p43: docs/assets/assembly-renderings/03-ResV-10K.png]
3. 10K: R9 <br>

At this point your board should look something like this

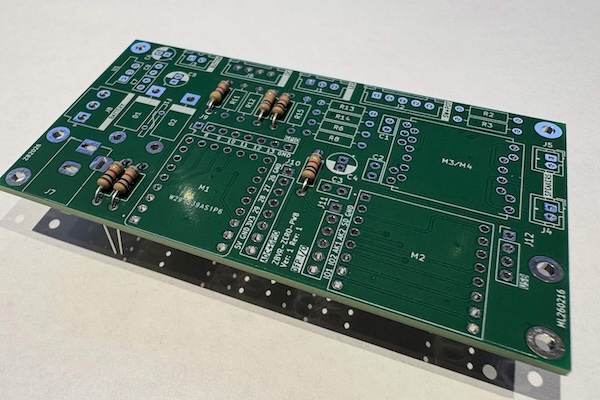
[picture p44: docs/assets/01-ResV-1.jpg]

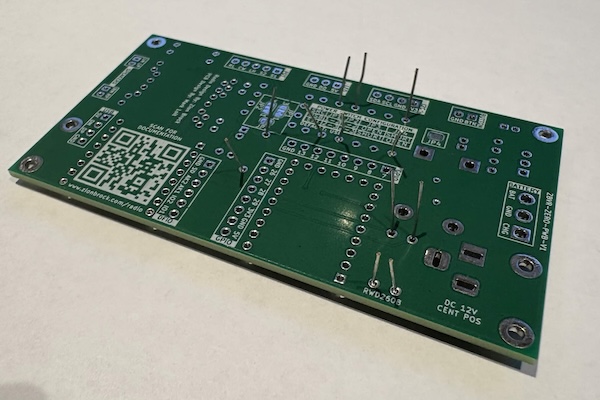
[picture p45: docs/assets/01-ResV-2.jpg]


Put the board in the holder

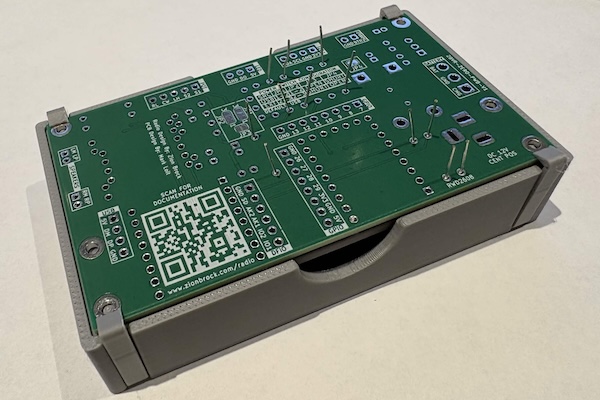
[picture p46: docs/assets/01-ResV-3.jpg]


Solder

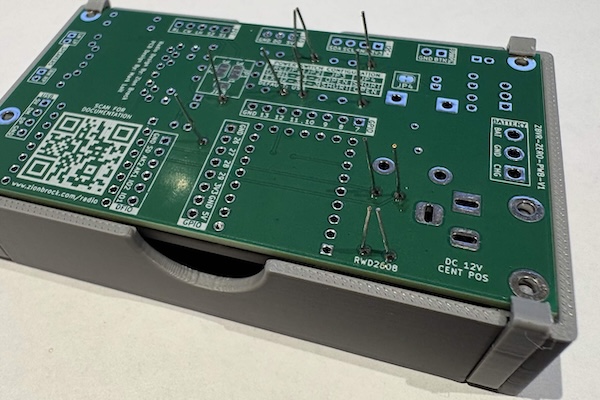
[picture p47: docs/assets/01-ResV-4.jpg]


Clip off excess lead

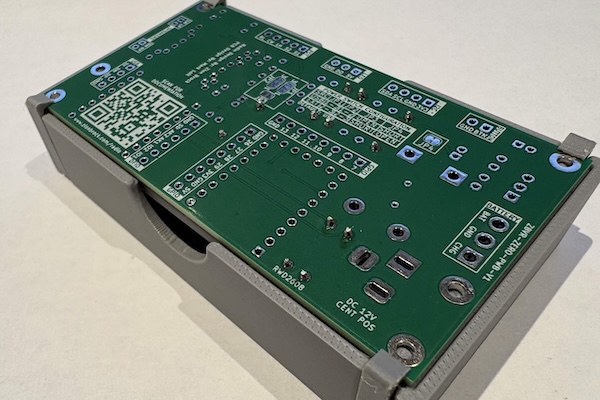
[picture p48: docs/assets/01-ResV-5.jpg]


[ResV-1K]: ./assets/assembly-renderings/01-ResV-1K.png "PCB Rendering, showing locations for 1K resistors"
[ResV-4K7]: ./assets/assembly-renderings/02-ResV-4K7.png "PCB Rendering, showing location for 4K7 resistor"
[ResV-10K]: ./assets/assembly-renderings/03-ResV-10K.png "PCB Rendering, showing location for 10K resistor"

[ResV-1]: ./assets/01-ResV-1.jpg "Current Component Side View"
[ResV-2]: ./assets/01-ResV-2.jpg "Current Solder Side View"
[ResV-3]: ./assets/01-ResV-3.jpg "Board in PCB Holder, unsoldered"
[ResV-4]: ./assets/01-ResV-4.jpg "Board in PCB Holder, soldered"
[ResV-5]: ./assets/01-ResV-5.jpg "Board in PCB Holder, clipped"

##### Horizontal Group

Now we're going to repeat the process for the horizontally aligned resistors

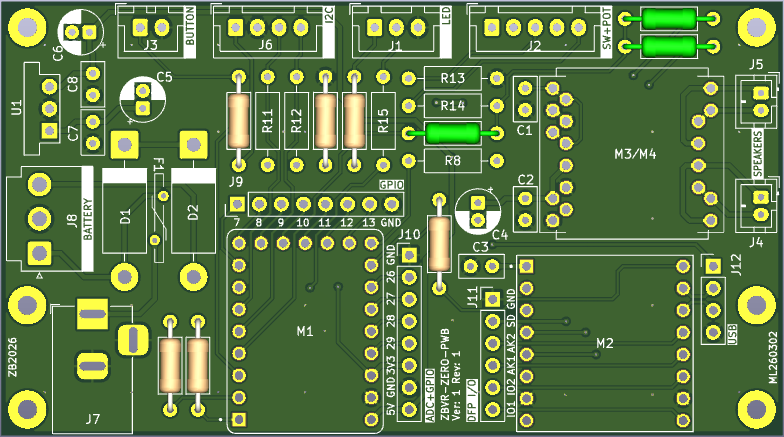
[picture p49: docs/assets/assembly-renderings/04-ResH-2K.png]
1. 2K: R2, R3, R6 <br>
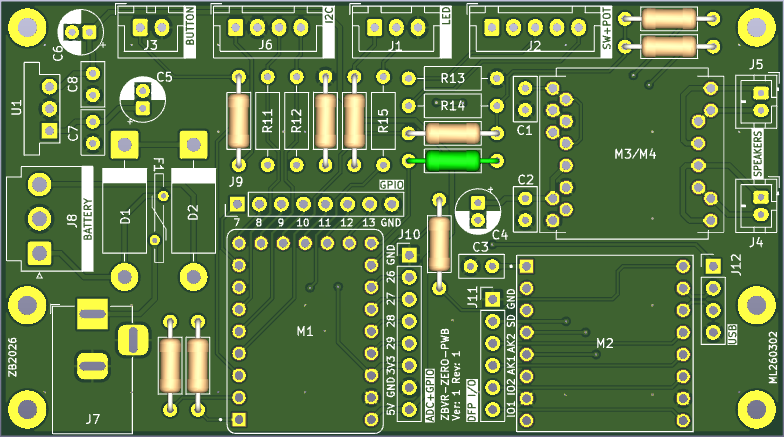
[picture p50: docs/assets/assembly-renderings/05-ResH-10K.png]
2. 10K: R8 <br>
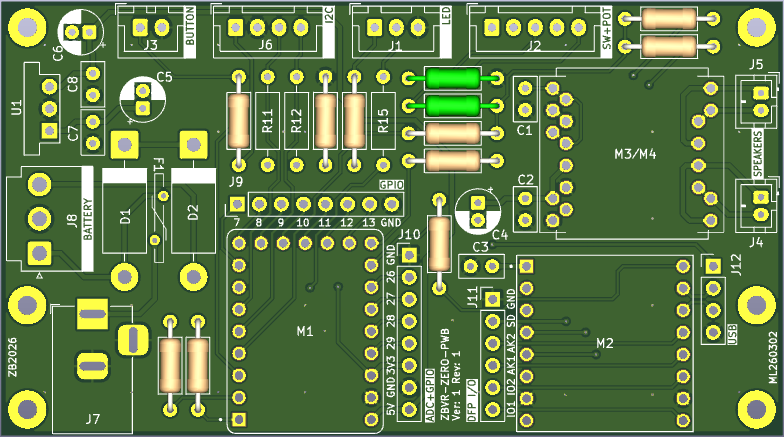
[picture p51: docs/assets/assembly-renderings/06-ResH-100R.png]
3. 100R: R13, R14 <br>

At this point your board should look something like this

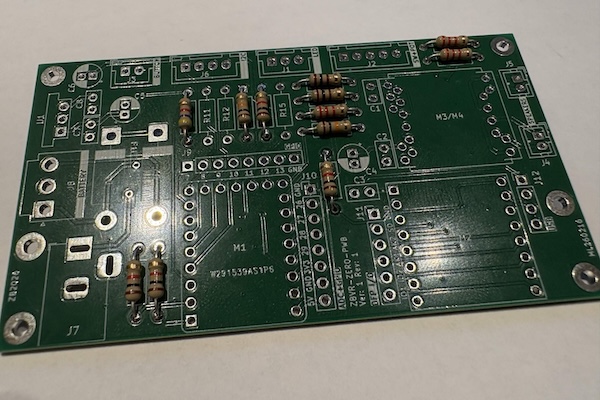
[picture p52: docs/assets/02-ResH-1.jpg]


Put the board in the holder, solder, and clip

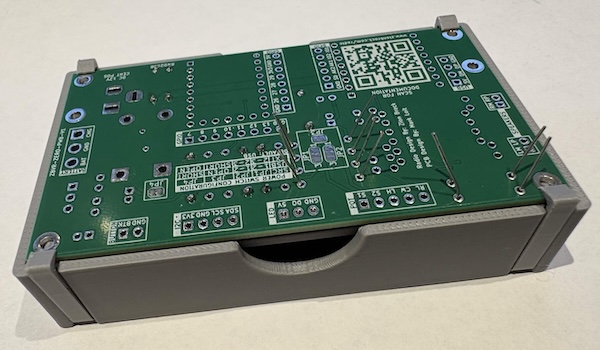
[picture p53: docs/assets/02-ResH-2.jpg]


Your board should now look something like this



[ResH-2K]: ./assets/assembly-renderings/04-ResH-2K.png "PCB Rendering, showing locations for 2K resistors"
[ResH-10K]: ./assets/assembly-renderings/05-ResH-10K.png "PCB Rendering, showing location for 10K resistor"
[ResH-100R]: ./assets/assembly-renderings/06-ResH-100R.png "PCB Rendering, showing locations for 100R resistors"

[ResH-1]: ./assets/02-ResH-1.jpg "Current Component Side View"
[ResH-2]: ./assets/02-ResH-2.jpg "Board in PCB Holder, unsoldered"
[ResH-3]: ./assets/02-ResH-3.jpg "Current Component Side View (soldered)"

#### Small Capacitors

Since we only have the 3 total small capacitors we can do them all at the same time. The process here is the same as with resistors. Note that like resistors, these small ceramic capacitors do not have a specific polarity, and can be soldered in either orientation.

1. 10nF/103: C1 (10,000pF) <br>
2. 100nF/104: C2, C3 (0.1uF) <br>

At this point your board should look something like this



Put the board in the holder, solder, and clip



[Cap-103]: ./assets/assembly-renderings/07-Cap-103.png "PCB Rendering, showing location for 10nF capacitor"
[Cap-104]: ./assets/assembly-renderings/08-Cap-104.png "PCB Rendering, showing locations for 100nF capacitors"

[SmCap-1]: ./assets/03-SmCap-1.jpg "Current Component Side View"
[SmCap-2]: ./assets/03-SmCap-2.jpg "Board in PCB Holder, unsoldered"

#### Speaker Connectors

The next step up in component height are the speaker connectors. In this case the connectors are self gripping, so we don't need the jig. Just press the connectors in, flip the board over, and solder the pins. We also don't need to clip the pins for these, or any of the connectors going forward. Please note the connector orientation in the photo below before soldering.

1. JST-PH2: J4, J5 <br>

At this point your board should look something like this



[Con-PH2]: ./assets/assembly-renderings/09-Con-PH2.png "PCB Rendering, showing locations for the PH2 connectors"

[Con-PH]: ./assets/04-Con-PH.jpg "Current Component Side View with PH connectors"

#### Front Panel Connectors

The next step up in component height are the front panel control connectors. In this case the connectors are not self gripping. Please note the connector orientation in the photo below before soldering.

1. JST-XH2: J3 <br>
2. JST-XH3: J1 <br>
3. JST-XH5: J2 <br>

At this point your board should look something like this



Now things get a little trickier. As the connectors are loose it can be difficult to flip the board over and put it in the jig. Another problem is due to the fact all the connectors are on one side, the jig won't put a flat/even force on them. Instead it tends to push them to the side. To sole this you can use the lead bending jig as a wedge on the opposite side to balance out the plate before soldering.



**Tip:** Alternatively, and probably easier here, is to just solder each connector individually outside the jig, using your finger to hold the connector flat to the board as you solder one of the pins to tack it in place. Once all are tacked in, you can proceed to solder the rest of the pins.

Once complete, your board should now look something like this



[Con-XH2]: ./assets/assembly-renderings/10-Con-XH2.png "PCB Rendering, showing location for the XH2 connector"
[Con-XH3]: ./assets/assembly-renderings/11-Con-XH3.png "PCB Rendering, showing location for the XH3 connector"
[Con-XH5]: ./assets/assembly-renderings/12-Con-XH5.png "PCB Rendering, showing location for the XH5 connector"

[Con-XH-1]: ./assets/05-Con-XH-1.jpg "Current Component Side View with XH connectors, unsoldered"
[Con-XH-2]: ./assets/05-Con-XH-2.jpg "Board in holder with XH connectors, and shim"
[Con-XH-3]: ./assets/05-Con-XH-3.jpg "Current Component Side View with XH connectors, soldered"

#### Module Connectors

Next up are the female headers for each of the modules on the board. These can be a bit floppy, as such I recommend installing the modules into the headers temporarily in order to steady and position them while you tack the headers to the board. Now you won't be able to put the board in the jig with the modules installed. Instead, solder a single pin from each of the header strips for each module to lock them in place. Carefully remove the module. Once all the module headers are installed, then put the board back in the jig and proceed to solder the remaining pins.

Note that the individual header strip designators `MxJxx` are not labelled on the PCB, only the modules themselves `Mx`, but it should be pretty obvious where each goes.

##### M1 - RP2040-Zero Connectors

The RP2040-Zero needs 3 connectors. Two 9pin, and one 5 pin.

1. M1 9 pin: M1J1, M1J3  <br>
2. M1 5 pin: M1J2 <br>

Install the RP2040-Zero module to hold the connectors steady, flip the board and solder one or two pins from each of the 3 header strips to lock them in place. Then carefully remove the RP2040-Zero 

[M1-HDR9]: ./assets/assembly-renderings/13-HDR-1x9.png "PCB Rendering, showing locations for the M1 9-pin headers"
[M1-HDR5]: ./assets/assembly-renderings/14-HDR-1x5.png "PCB Rendering, showing location for the M1 5 pin header"

##### M2 - DFPlayer Connectors

The DFPlayer-mini needs two 8-pin connectors.

1. M2 8 pin: M2J1, M2J2  <br>

[M2-HDR8]: ./assets/assembly-renderings/15-HDR-1x8.png "PCB Rendering, showing locations for the M2 8-pin headers"

Install the DFPlayer module to hold the connectors steady, flip the board and solder one or two pins from each of the 2 header strips to lock them in place. Then carefully remove the DFPlayer. 

##### M3/M4 - Amplifier Connectors

At this point we come to a slight fork in the road. The board has been designed to support either the `DFR0119-O` amplifier module from DFRobot/DigiKey, or the generic `PAM8403` amplifier module from Amazon (or other sources). If you plan to use the DFRobot amplifier module from the PCB BOM, Follow the [M3 Amplifier](#M3AMP) instructions. If you plan to use the generic `PAM8403` amplifier module from Amazon, proceed to the [M4 Amplifier](#M4AMP) section.

######    M3 Amplifier

1. M3 6 pin: M3J1  <br>
2. M3 4 pin: M3J2  <br>

Install the amplifier module to hold the connectors steady, flip the board and solder one or two pins from each of the 2 header strips to lock them in place. Then carefully remove the amplifier. 

[Continue](#AMPWRAP) below.

[M3-HDR6]: ./assets/assembly-renderings/16-HDR-1x6.png "PCB Rendering, showing location for the M3 6-pin header"
[M3-HDR4]: ./assets/assembly-renderings/17-HDR-1x4.png "PCB Rendering, showing location for the M3 4-pin header"

######    M4 Amplifier

1. M4 3 pin: M4J1  <br>
2. M4 2 pin: M4J2, M4J3, M4J4  <br>

Install the amplifier module to hold the connectors steady, flip the board and solder one or two pins from each of the 4 header strips to lock them in place. Then carefully remove the amplifier. 

[Continue](#AMPWRAP) below.

[M4-HDR3]: ./assets/assembly-renderings/18-HDR-1x3.png "PCB Rendering, showing location for the M4 3-pin header"
[M4-HDR2]: ./assets/assembly-renderings/19-HDR-1x2.png "PCB Rendering, showing locations for the M4 2-pin headers"

---
 ***Common To Both Amplifier Modules***

Once all the module headers are tacked in, and the modules removed again, the board can be placed into the jig and the remainder of the pins soldered.

#### Electrolytic Capacitor

Our final, and tallest component is the 10uF electrolytic capacitor. Unlike the capacitors, and resistors, we did before. This capacitor has a defined orientation and must be installed in the correct orientation. The soldering process remains the same as the resistors, except we can't use the jig here. 

1. 10uF: C4 <br>

Note the white marking on the PCB on the one side of the circle



This the white stripe with the `-` on the side of the capacitor must align with the white marking on the board.



Once the cap is soldered, and clipped, your board should look something like this



[Cap-10u]: ./assets/assembly-renderings/20-Cap-10u.png "PCB Rendering, showing location for the 10uF capacitor"

[Cap-1]: ./assets/07-Cap-1.jpg "Close up showing silkscreen marking for the capacitor, unsoldered"
[Cap-2]: ./assets/07-Cap-2.jpg "close up showing the markings on  the capacitor"
[Cap-3]: ./assets/07-Cap-3.jpg "image of board with capacitor, soldered"

---

#### FIN!
Congratulations on making it this far, you now have a fully populated PCB for the Vintage Radio. At this point, before powering the board, you should visually inspect all your soldered joints to make sure you didn't miss any, or that there are no shorts between pins. If you must touch up, you can use the soldering jig, without the spring-plate, to cradle the board (without modules) for you. If you have a meter, you can test for shorts between adjacent pins and continuity between source and destination points (you'll need to read the schematic to determine the from-to points to measure). 

All that's left to do for the PCB now is install the modules, and program the micro. Be sure to check the [Wiring Harness Assembly Guide](./Wiring%20Harness%20Assembly%20Guide.md) to complete the wiring for the radio.



[fin]: ./assets/final-assy.jpg "assembled radio board"
---

##  Lead Bending Tool



The Bending aid is designed to allow for accurately bending the leads of 1/4W resistors for a standard 0.4in hole spacing. The jig thickness is also such that if the leads are cut flush with the bottom, it should be just about perfect for a standard 1.6mm (0.064in) PCB. Though I would recommend trimming after soldering.

The bending jig is on the plate in the `.3MF` print profile for [assembly-jigs][3]
or the `STL` can be [downloaded directly](/assets/soldering-aids/bend-aid-new.stl).

**Note:** that these are the same models as are on the radio project page over on [MakerWorld][4]. 




[bendaid]: ./assets/bend-aid.jpg "component lead bending jig"
[bend1]: ./assets/bend1.jpg "resistor in bending jig"
[bend2]: ./assets/bend2.jpg "resistor in bending jig, with bent leads"
---

##  PCB Holder



The PCB holding jig is intended to work like a 3rd hand, helping to support components as you are soldering. 

All the parts for the PCB holder jig are on the plate in the `.3MF` print profile for [assembly-jigs][3]
or the individual  `STL` files can be downloaded:

- [main holder](/assets/soldering-aids/soldering-aid.stl) qty: 1
- [clip](/assets/soldering-aids/soldering-aid-clip.stl) qty: 2
- [plate](/assets/soldering-aids/soldering-aid-plate.stl) qty: 1
- [spring](/assets/soldering-aids/soldering-aid-spring.stl) qty: 2

**Note:** that these are the same models as are on the radio project page over on [MakerWorld][4]. 

The clips simply slide into their respective grooves on the main holder body. (Photos are of an earlier prototype that was asymmetrical, the download is completely symmetrical in its design)



To assemble the plate, the 2 springs need to be glued to the plate in the provided divots. You may need to file off any elephants foot, and the corners of the nub on the spring for it to sit firm and flat in the plate feature. Simply put a drop of CA glue in the divot and then press in the nub of the spring. (Photos are of an earlier prototype that was asymmetrical, the download is completely symmetrical in its design)




[pcbaid]: ./assets/pcb-aid.jpg "PCB aid with plate"
[pcbaid1]: ./assets/holder.jpg "PCB aid with clips in place"
[pcbaid2]: ./assets/blankplate.jpg "PCB aid plate, no springs installed"
[pcbaid3]: ./assets/plate.jpg "PCB aid plate with springs in place"

[3]: /assets/assembly-jigs.3mf
[4]: https://makerworld.com/en/models/2163838-my-vintage-radio-offline-am-style-music-player

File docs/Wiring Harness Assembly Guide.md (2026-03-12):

# Wiring Harness Assembly Guide



In this guide we'll assemble the wiring harnesses for front panel/controls of the vintage radio. For the intermediate/advanced users here is the summary wiring diagram depicting the three front-panel harnesses.



[intro]: ./assets/wiring-photos/parts.jpg "photo of all the wiring parts"
[diag]: ./assets/assembly-renderings/all-harnesses.png "diagram depicting all the wiring harnesses"

## Materials

### Components
- 10K Potentiometer with switch
- Pushbutton
- LED (3mm or 5mm)
- 2x JST XHP-2 2 pin housings
- 1x JST XHP-3 3 pin housing
- 1x JST XHP-5 5 pin housing
- 2x JST-XH 6in (152mm) 22AWG pre-crimped wire lead (ASXHSXH22K152)
- 4x JST-XH 12in (305mm) 22AWG pre-crimped wire lead (ASXHSXH22K305) *

**Note:** The 12in wire leads are intended to be cut in half to each produce two single-ended 6in wire leads. In total we need seven 6in single-ended leads for all the harnesses here. The one left-over can be saved for another unit if building more than one.

### Required Materials
- Solder

### Optional Materials
- 2 pcs 0.062in (1.6mm) pre-cut heatshrink tubing approx 0.5in (6mm) long 
- 5 pcs 0.125in (3mm) pre-cut heatshrink tubing approx 0.5in (6mm) long

## Tools

### Required Tools
- Soldering iron
- Wire cutters
- Wire strippers

### Optional Tools
- Tweezers
- Digital volt meter
- Heat gun
- Permanent marker
- Ruler

---

## Assembly

### Wire Lead Prep



Before we begin with the individual harness, we want to prepare our 6inch single-ended wire leads, that will be used in the individual harnesses.

#### Parts

- 4x JST XH 12in 22AWG pre-crimped wire lead 

#### Steps

For each of the 12 inch wire leads perform the following to produce two 6 inch single-ended leads each (8 in total)

1. Fold the 12in wire lead tightly in half to find the middle <br>
2. Cut the wire lead at the fold to form 2 6in wire leads with a crimp on one end <br>
3. Strip the cut ends removing about 10mm of insulation <br>
4. Twist strands together tightly <br>

When done you should have 8 total single-ended leads. Set one aside and save for another build, only 7 are needed for the harnesses below. 


[wire]: ./assets/wiring-photos/00-leads.jpg "photo of all the button wiring parts"
[wire01]: ./assets/wiring-photos/00-fold.jpg "folded wire lead"
[wire02]: ./assets/wiring-photos/00-cut.jpg "cut wire lead"
[wire03]: ./assets/wiring-photos/00-strip.jpg "stripped wire lead"
[wire04]: ./assets/wiring-photos/00-twist.jpg "wire lead with twisted strands"
[wire05]: ./assets/wiring-photos/00-done.jpg "completed single ended wire leads"

---

### Button Cable


Polarity is not important for the button so we don't need to worry about which pin connects to which terminal of the pushbutton.



#### Parts

- 1x Pushbutton
- 1x JST XHP-2 2 pin housing
- 2x JST XH 12in 22AWG pre-crimped single-ended wire lead (prepared above)

#### Optional Materials
- 2x 0.062in pre-cut heatshrink tubing (smaller diameter)

**Note:** Check that the heatshrink tubing will slide over the crimped end of the wire leads. If not please ensure that the tubing used in step 6 below is slipped onto the wires before step 1

#### Steps

1. Bend the stripped ends in the middle into a L shape <br>
2. carefully fish the end of one of the wires, be sure to get all strands through the hole on the tab of the button <br>
3. Fold the bend all the way over back to parallel with the rest of the wire to hold the lead in position <br>
4. Solder the lead to the tab keeping the wire coming as straight off the tab as possible 
5. Repeat steps 2-4 for the other lead <br>
6. If adding heatshrink, follow the optional steps now before continuing
7. insert the crimped ends of the wire leads into the XHP-2 housing <br>

##### Optional steps:

1. slip one of the strips of heatshrink tubing over the crimped end of a lead and slide up and over the soldered connection at the button. Do this for each of the wire leads/connections.<br>

2. using a heat gun or other heat source heat the tubing to shrink it for a secure fit over the connections.<br>

The finished cable should look something like this


[button]: ./assets/wiring-photos/01-button-parts.jpg "photo of all the button wiring parts"
[button-harness]: ./assets/assembly-renderings/button-harness.png "diagram depicting the button wiring harnesses"
[btn01]: ./assets/wiring-photos/00-bend.jpg "bent wire lead end"
[btn02]: ./assets/wiring-photos/01-02.jpg "inserted wire lead"
[btn03]: ./assets/wiring-photos/01-03.jpg "wire lead folded over"
[btn05]: ./assets/wiring-photos/01-05.jpg "soldered wire leads"
[btn07]: ./assets/wiring-photos/01-06.jpg "leads inserted into XHP-2 housing"
[btn-opt1]: ./assets/wiring-photos/01-07.jpg "heatshrink over tabs"
[btn-opt2]: ./assets/wiring-photos/01-08.jpg "heatshrink-shrunk"
[btn-done]: ./assets/wiring-photos/01-done.jpg "completed button harness"

---

### LED Cable


Note that for the LED pin 2 of the XHP-3 connector remains unused for a standard LED. 



#### Parts

- 1x LED
- 1x JST XHP-3 3 pin housing
- 1x JST XHP-2 2 pin housing
- 2x JST XH 6in 22AWG pre-crimped wire leads (double-ended)

#### Steps

1. Mark Pin 1 on both XHP housings with a permanent marker to make identification easier. <br>
2. Install one end of one of the leads into the pin 1 location of the XHP-3 housing <br>
3. Install the other end of the lead into the pin 1 position of the XHP-2 housing <br> 
4. Install one end of the remaining lead into the pin 3 position of the XHP-3 housing <br>
5. Install the other end of the lead into the pin 2 position of the XHP-2 housing <br>
6. Insert the legs of the LED into the XHP-2 housing, with the long leg going into the pin 1 mating position, and the short leg into the pin 2 mating position. Gently push the LED as far as it will go. When fully inserted, only the tip of the longer LED leg should protrude out the other side of the housing. <br>

The finished cable should look something like this


[led]: ./assets/wiring-photos/02-LED-parts.jpg "photo of all the LED wiring parts"
[led-harness]: ./assets/assembly-renderings/LED-harness.png "diagram depicting the LED wiring harnesses"
[led01a]: ./assets/wiring-photos/02-01a.jpg "XHP connectors, unmarked"
[led01b]: ./assets/wiring-photos/02-01b.jpg "XHP connectors marked"
[led02]: ./assets/wiring-photos/02-02.jpg "XHP-03 pin1 installed"
[led03]: ./assets/wiring-photos/02-03.jpg "XHP-02 pin1 installed"
[led04]: ./assets/wiring-photos/02-04.jpg "XHP-03 pin3 installed"
[led05]: ./assets/wiring-photos/02-05.jpg "XHP-02 pin2 installed"
[led06a]: ./assets/wiring-photos/02-06a.jpg "bent wire lead end"
[led06b]: ./assets/wiring-photos/02-06b.jpg "bent wire lead end"
[led06c]: ./assets/wiring-photos/02-06c.jpg "bent wire lead end"
[led-done]: ./assets/wiring-photos/02-done.jpg "completed LED wiring harness"

---

### Potentiometer Cable 



The final wiring harness is the potentiometer, and is the most complex. While the orientation does not matter for the switch portion, we do need to pay close attention to the orientation for the actual potentiometer (analog) portion.


<br>(colours for clarity only)

#### Parts

- 1x 10K Potentiometer with switch
- 1x JST XHP-5 5 pin housing
- 5x JST XH 12in 22AWG pre-crimped single-ended wire lead (prepared above)

#### Optional Materials
- 5x 0.125in pre-cut heatshrink tubing (larger diameter)

**Note:** Check that the heatshrink tubing will slide over the crimped end of the wire leads. If not please ensure that the tubing used in step 7 below is slipped onto the wires before step 1

#### Steps

1. Mark Pin 1 on the XHP-5 housing with a permanent marker to make identification easier. <br>
2. Bend the stripped ends in the middle into a L shape <br>
3. carefully fish the end of one of the wires, be sure to get all strands through the <br> hole on the tab of the button
4. Fold the bend all the way over back to parallel with the rest of the wire to hold the lead in position <br>
5. solder the lead to the tab keeping the wire coming as straight off the tab as possible 
6. repeat steps 3-5 for each of the 4 remaining terminals on the pot <br>   
7. If adding heatshrink, follow the optional steps now before continuing
8. Locate the two leads coming from the switch terminals on the back of the potentiometer. Insert the crimps into the pin1 and pin 2 positions of the XHP-5 housing. Order does not matter here. <br>
9. with the shaft of the potentiometer facing away from you, and the 3 terminals facing down to the floor, locate the lead connected to the right-most terminal, insert the crimped end of lead into the pin 3 position of the XHP-5 housing. <br> 
10. with the shaft of the potentiometer facing away from you, and the 3 terminals facing down to the floor, locate the lead connected to the centre terminal, insert the crimped end of lead into the pin 4 position of the XHP-5 housing.  <br>
11. insert the crimped end of the remaining lead into the pin 5 position of the XHP-5 housing <br>

##### Optional steps:

1. slip one of the strips of heatshrink tubing over the crimped end of a lead and slide up and over the soldered connection at the button. Do this for each of the wire leads/connections.<br>

2. using a heat gun or other heat source heat the tubing to shrink it for a secure fit over the connections.<br>

The finished cable should look something like this


[pot]: ./assets/wiring-photos/03-potentiometer-parts.jpg "photo of all the potentiometer wiring parts"
[pot-harness]: ./assets/assembly-renderings/pot-harness.png "diagram depicting the potentiometer wiring harnesses"
[pot01a]: ./assets/wiring-photos/03-01a.jpg "XHP connector, unmarked"
[pot01b]: ./assets/wiring-photos/03-01b.jpg "XHP connector, marked"
[pot02]: ./assets/wiring-photos/00-bend.jpg "bent wire lead end"
[pot03]: ./assets/wiring-photos/03-03.jpg "potentiometer with lead through a tab"
[pot04]: ./assets/wiring-photos/03-04.jpg "potentiometer with lead folded back"
[pot06]: ./assets/wiring-photos/03-06.jpg "potentiometer with leads soldered"
[pot08]: ./assets/wiring-photos/03-08.jpg "harness with pins 1 & 2 installed in XHP connector"
[pot09a]: ./assets/wiring-photos/03-09a.jpg "rightmost lead singled out"
[pot09b]: ./assets/wiring-photos/03-09b.jpg "harness with pin 3 installed in XHP connector"
[pot10]: ./assets/wiring-photos/03-10.jpg "harness with pin 4 installed in XHP connector"
[pot11]: ./assets/wiring-photos/03-11.jpg "harness with pin 5 installed in XHP connector"
[pot-opt1]: ./assets/wiring-photos/03-opt1.jpg "heatshrink slipped over connections"
[pot-opt2]: ./assets/wiring-photos/03-opt2.jpg "heatshrink after being shrunk"
[pot-done]: ./assets/wiring-photos/03-done.jpg "completed potentiometer harness"

---

## Fin

Congratulations on making it to the end. You now have all the wiring harnesses you need to complete your vintage radio. Assuming you have soldered up your PCB, and printed your enclosure. Now is the time to put it all together and enjoy the fruits of your labour.



[fin]: ./assets/wiring-photos/all-harnesses.jpg "photo of all the completed wiring harnesses"

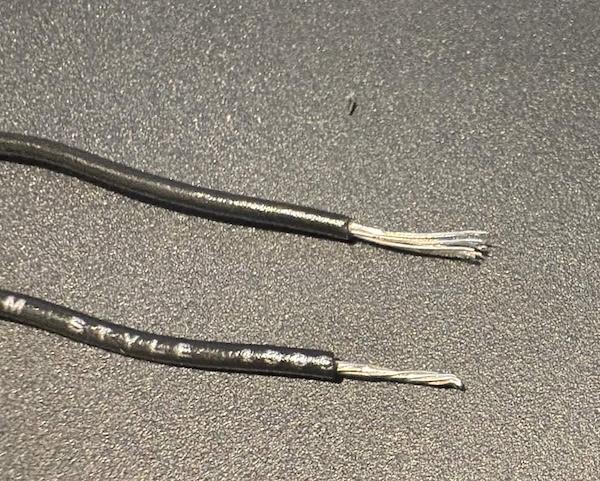
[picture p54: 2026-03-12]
docs/assets/wiring-photos/00-strip-twist.jpg

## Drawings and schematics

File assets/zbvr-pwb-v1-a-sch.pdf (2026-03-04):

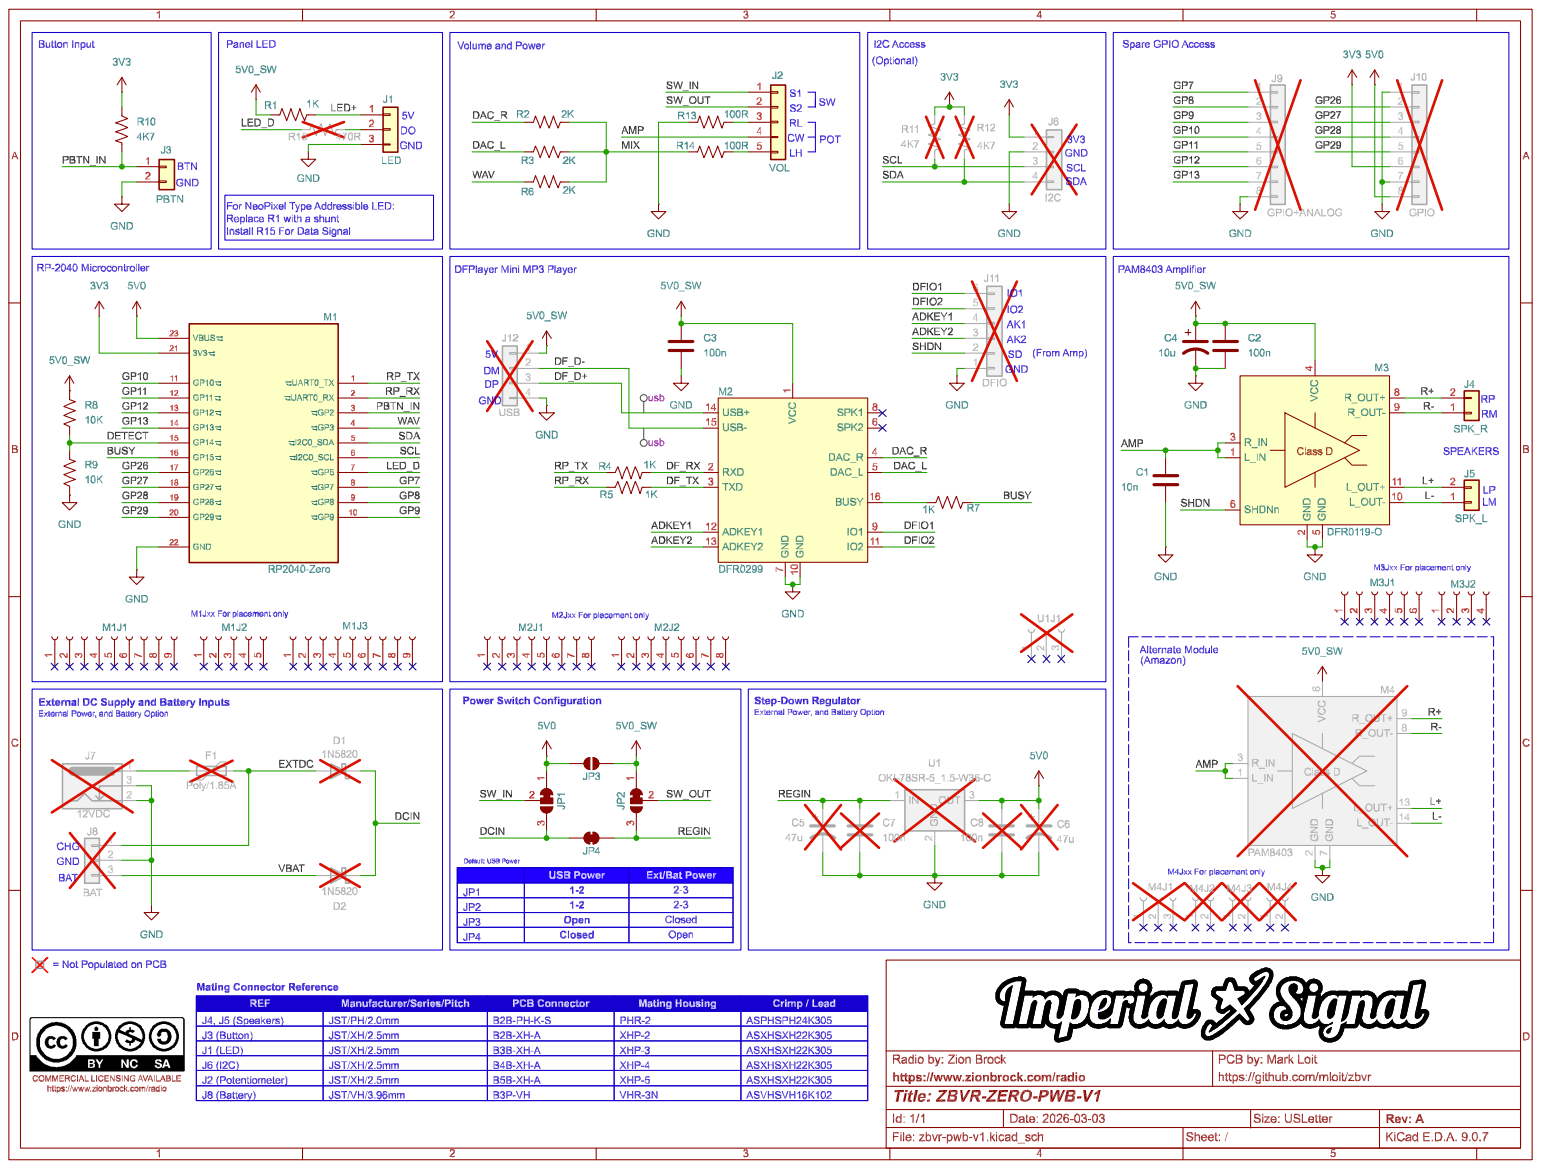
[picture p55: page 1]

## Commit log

2026-03-04 Update README.md
    added link to Zion's PCB page
2026-03-05 Update README.md
    updated pcbway link
2026-03-11 Added PCB Assembly Guide
    First pass, to get people going
    [assembly-jigs.3mf, bend-aid-new.step, bend-aid-new.stl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]
2026-03-11 Update PCB Assembly Guide.md
    added breaks in the lists for the images
2026-03-11 Update PCB Assembly Guide.md
    Formatting fixes for GitHub rendering
2026-03-11 Update PCB Assembly Guide.md
    fixed link to schematics
2026-03-11 Update PCB Assembly Guide.md
    added a note about unpopulated components
2026-03-11 Update README.md
    added alternate DigiKey BOM
2026-03-12 Updated PCB Assembly Guide
    added note about capacitor values
2026-03-12 Update PCB Assembly Guide.md
2026-03-12 Added Wiring Harness instructions
2026-03-21 Update PCB Assembly Guide.md
    Corrected links for the step and stl assets
2026-06-08 Big Speaker
    Guide and models for using a bigger speaker with the radio
    [GRS-3AS-4-cup.stl, GRS-3AS-4-ring.stl, big-speaker.3mf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]
2026-09-28 BOMs added
    Added links to Amazon parts and the various versions of the component BOM's at DigiKey
2026-09-29 power supply
    - Added a note about the required power supply for the battery option
    - Added support link

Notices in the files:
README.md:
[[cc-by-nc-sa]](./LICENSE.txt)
